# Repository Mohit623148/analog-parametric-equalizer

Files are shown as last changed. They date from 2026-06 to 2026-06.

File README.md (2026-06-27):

# 🎛️ 5-Band Analog Parametric Audio Equalizer

> A fully analog, State Variable Filter (SVF) based parametric equalizer covering the full audio spectrum (20 Hz – 20 kHz), designed as Minor Project II at NIT Andhra Pradesh.

---

## 📌 Project Overview

This project implements a **5-band analog parametric equalizer** using the **KHN (Kerwin-Huelsman-Newcomb) State Variable Filter** topology. It features independent control of center frequency, gain (±9 dB), and Q (bandwidth) for each band — without any cross-coupling between parameters.

The complete design flow covers:
- Transfer function derivation and circuit analysis
- LTspice behavioral and SPICE-level simulation
- Proteus verification with exact TL074CDR models
- KiCad schematic capture (EESchema) and 4-layer PCB layout (PCBnew)

---

## 🗂️ Repository Structure

```
analog-parametric-equalizer/
│
├── ltspice/                  # LTspice simulation files (.asc)
│   ├── full_circuit.asc      # Complete cascaded equalizer
│   ├── low_shelf.asc
│   ├── band1_250Hz.asc
│   ├── band2_800Hz.asc
│   ├── band3_2500Hz.asc
│   └── high_shelf.asc
│
├── kicad/                    # KiCad project files
│   ├── Mini_project.kicad_pro
│   ├── Mini_project.kicad_sch
│   ├── Mini_project.kicad_pcb
│   └── Mini_project.kicad_prl
│
├── docs/                     # Documentation
│   ├── Project_report.pdf    # Full 27-page project report
│   └── ppt_EQ.pptx           # Presentation slides
│
├── images/                   # Screenshots and renders
│   ├── ltspice_full_circuit.png
│   ├── kicad_schematic.png
│   ├── pcb_top_view.png
│   ├── pcb_3d_isometric.png
│   └── sim_smile_curve.png
│
└── README.md
```

---

## ⚙️ Filter Architecture

The equalizer uses a **cascaded (series)** signal chain — each filter block feeds the next, which simplifies gain staging and inter-band tuning.

```
Audio In (3.5mm TRRS)
    │
    ▼
[DC Block + Impedance Match]  →  [ESD Protection — TVS1400DRV]
    │
    ▼
[Low Shelf Filter]        fc: 120–500 Hz,    Gain: ±9 dB
    │
    ▼
[SVF Band 1 — Bass]       f₀: 120–500 Hz,   Gain: ±9 dB,  Q: adjustable
    │
    ▼
[SVF Band 2 — Midrange]   f₀: 400–1600 Hz,  Gain: ±9 dB,  Q: adjustable
    │
    ▼
[SVF Band 3 — Upper Mid]  f₀: 1.2–5 kHz,    Gain: ±9 dB,  Q: adjustable
    │
    ▼
[High Shelf Filter]        fc: 1.2–5 kHz,   Gain: ±9 dB
    │
    ▼
[Output Buffer + ESD]  →  Audio Out (3.5mm TRRS)
```

### Band Summary

| Band | Center Freq | Tuning Range | Integrator Caps | Frequency Pot |
|---|---|---|---|---|
| Low Shelf | 120–500 Hz  | Adjustable | C11 = 80 nF | RV2 (100kΩ dual)  |
| Band 1 Bass  | 250 Hz | 120–500 Hz | C3, C4 = 33 nF  | RV3/RV4 (10kΩ dual)|
| Band 2 Mid | 800 Hz | 400–1600 Hz  | C7, C8 = 10 nF  | RV7/RV9 (10kΩ dual)|
| Band 3 Hi-Mid| 2.5 kHz | 1.2–5 kHz | C9, C10 = 3.3 nF| RV10/RV12 (10kΩ dual)|
| High Shelf | 1.2–5 kHz | Adjustable | C2 = 6.8 nF | RV15 (100kΩ dual) |

---

## 🔬 Key Design Achievements

### Q–Gain Decoupling
In a standard SVF, bandpass peak = Q × Vin, meaning tuning Q inadvertently changes the boost/cut magnitude. This was solved by relocating the Q-control resistor to the BP output feedback path of the summing amplifier — peak amplitude is now constant at Vin, fully independent of Q.

### Dual-Gang Frequency Control
Center frequency ω₀ = 1/(RC) requires both integrators to track the same R simultaneously. Dual-gang potentiometers ensure both integrators always see equal resistance, maintaining SVF symmetry at any frequency setting.

### SVF Bandpass Transfer Function

```
              (ω₀/Q) · s
H(s) = ─────────────────────────────
         s² + (ω₀/Q)·s + ω₀²
```

---

## 🧰 Components

**Core ICs:**
- `TL074CDR` — Quad JFET-input op-amp, SOIC-14 (×5, giving 20 op-amp stages)
- `TVS1400DRV` — TVS ESD protection array (×2, at input and output)

**Op-Amp Key Specs (TL074CDR):**

| Parameter | Value |
|---|---|
| Supply voltage  | ±15 V |
| Slew rate | 13 V/µs |
| GBW product | 3 MHz |
| Input bias | 65 pA |
| Noise voltage | 18 nV/√Hz |

**Total BOM:** 89 components, 56 fixed resistors, 11 capacitors, 16 potentiometers, 2 audio connectors.

---

## 📊 Simulation Results

All five filter blocks were simulated in **LTspice XVII** (AC sweep, 20 Hz – 20 kHz, 1000 pts/decade) and verified in **Proteus** using exact TL074CDR SPICE models.

| Block | Target f₀/fc | Result | Gain Range | Status  |
|---|---|---|---|---|
| Low Shelf | 250 Hz nominal | ~250 Hz, tunable 120–500 Hz | ±9 dB | ✅ Pass |
| Band 1 (Bass)  | 250 Hz | ~250 Hz, tunable 120–500 Hz | ±9 dB | ✅ Pass |
| Band 2 (Mid) | 800 Hz | ~800 Hz, tunable 400–1600 Hz| ±9 dB | ✅ Pass |
| Band 3 (Hi-Mid)| 2.5 kHz | ~2.5 kHz, tunable 1.2–5 kHz | ±9 dB  | ✅ Pass |
| High Shelf | 2.3 kHz nominal| ~2.3 kHz, tunable 1.2–5 kHz | ±9 dB  | ✅ Pass |

**Preset EQ responses verified:** V-Shape (Smile Curve), Vocal Boost

---

## 🖥️ PCB Design

Designed in **KiCad PCBnew v9.0** with a 4-layer FR-4 stackup:

| Layer | Role |
|---|---|
| F.Cu (Top) | Signal routing, component placement |
| In1.Cu | Solid GND plane |
| In2.Cu | ±15 V power distribution |
| B.Cu (Bot) | Secondary signal routing |

**PCB Stats:** 1,468 track segments · 150 vias · A3 drawing sheet

Layout follows signal-flow order (left → right), with decoupling caps adjacent to op-amp supply pins and all potentiometers along one edge for front-panel mounting.

---

## 🛠️ Tools Used

| Tool | Version | Purpose |
|---|---|---|
| LTspice XVII | — | AC sweep simulation |
| Proteus Design Suite | — | SPICE verification |
| KiCad EESchema | 9.0 | Schematic capture |
| KiCad PCBnew | 9.0 | PCB layout |

---

## 👥 Team

| Name | Roll No. |
|---|---|
| Mohit Kumar Gupta | 623148 |
| Satyam Kumar | 623172 |
| Vishal Ray | 622271 |

**Guide:** Dr. M. C. Raju, Assistant Professor, DECE, NIT Andhra Pradesh
**Course:** Minor Project II (EC399) · Academic Year 2025–26

---

## 📄 License

This project is shared for educational and reference purposes. Feel free to study, fork, and build upon it — attribution appreciated.

---

## 🔮 Future Work

- [ ] PCB fabrication and hardware assembly
- [ ] Audio characterisation using REW (THD+N, noise floor, dynamic range)
- [ ] Enclosure and front-panel design for all 16 potentiometers
- [ ] Expand to 7 or 10 bands with additional SVF stages
- [ ] PCB noise optimisation based on measured results

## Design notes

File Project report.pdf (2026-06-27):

``

## NATIONAL INSTITUTE OF TECHNOLOGY ANDHRA PRADESH

Department of Electronics and Communication Engineering

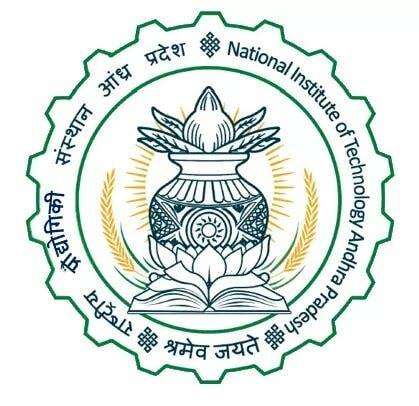
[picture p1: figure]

# Design and Implementation of a Multi-Band Analog Audio Equalizer

## PROJECT REPORT

Minor Project II (EC399)

Presented by: | Mohit Kumar Gupta [623148]
Satyam Kumar | [623172]
Vishal Ray | [622271]
Guide: | Dr. M. C. Raju Assistant Professor NIT Andhra Pradesh

Multi-Band Analog Audio Equalizer — Final Project Report | NIT Andhra Pradesh, Dept. of ECE
Page 2 of 27 | Minor Project II (EC) | April 2026

CERTIFICATE This is to certify that the project report entitled "Design and Implementation of a Multi-Band Analog Audio Equalizer" is a Bonafide record of the work carried out by Mohit Kumar Gupta (623148), Satyam Kumar (623172), and Vishal Ray (622271) in fulfilment of the requirements for the award of the degree of Bachelor of Technology in Electronics and Communication Engineering at the

National Institute of Technology Andhra Pradesh.

## This work has been carried out under my supervision during the

academic year 2025–2026.

## Guide:

Dr. M. C. Raju | Dr. B. Narasimha Rao
Assistant Professor | Head of Department
DECE | DECE
NIT Andhra Pradesh | NIT Andhra Pradesh

Page 3 of 27 | Minor Project II (EC) | April 2026

## ACKNOWLEDGEMENT

We would like to express our sincere gratitude to our project guide,

## Dr. M. C. Raju, for his continuous support, valuable guidance, and encouragement throughout the development of this project. His expertise and insights were instrumental in shaping the direction and

successful completion of this work.

## We also thank the faculty members of the Department of Electronics and Communication Engineering, NIT Andhra Pradesh, for providing

the necessary resources and a supportive academic environment.

## We would like to extend our special thanks to the judges for their valuable suggestions during the mid-review and for their time and

constructive feedback, which helped improve the quality of our work.

## We are grateful to our friends and peers for their support and constructive discussions. Finally, we extend our heartfelt thanks to

our families for their constant motivation and encouragement.

Page 4 of 27 | Minor Project II (EC) | April 2026

## ABSTRACT This project presents the design and implementation of a 5-band analog parametric audio equalizer covering the full audio frequency range from 20 Hz to 20 kHz. The system is based on the State Variable Filter (SVF) topology, enabling independent control of

center frequency, gain, and bandwidth (Q-factor) for each band.

## The equalizer consists of three tunable peaking filters centered at 250 Hz, 800 Hz, and 2.5 kHz, along with low and high shelving filters for bass and treble control. The design uses TL074 JFET-input

operational amplifiers to achieve low noise, high input impedance, and adequate bandwidth for audio applications.

## A complete signal chain is developed, including input/output interfacing through 3.5 mm TRRS audio jacks, ESD protection using TVS diodes, and proper impedance matching. The circuit is designed and verified using LTspice and Proteus simulations, followed by

schematic capture and PCB layout using KiCad.

## The results demonstrate accurate frequency response, ±9 dB gain control, and stable performance across all bands. The project highlights the practical implementation of analog filter design concepts and provides a foundation for further development into a

fully functional audio processing device.

Page 5 of 27 | Minor Project II (EC) | April 2026

## Table of Contents

Page 6 of 27 | Minor Project II (EC) | April 2026

Page 7 of 27 | Minor Project II (EC) | April 2026

## 1. Introduction

### 1.1 Background and Motivation

Audio equalization is the process of selectively adjusting the amplitude of specific frequency bands within an audio signal. It is fundamental to professional audio production, live sound reinforcement, acoustic correction, and consumer hi-fi systems. Without equalization, audio systems suffer from uneven frequency response introduced by room acoustics, speaker colorations, and source limitations — all of which degrade the perceived quality of sound.
Digital equalizers have become dominant in modern audio processing owing to their flexibility and precision. However, analog equalizers remain indispensable in applications demanding zero latency, simplicity of hardware, and the characteristic warmth that continuous-time processing preserves. For educational purposes, an analog parametric equalizer also serves as a comprehensive vehicle for applying filter theory, op-amp circuit design, and frequency-domain analysis to a real-world problem.

### 1.2 Project Objectives

- Design a 5-band analog parametric equalizer covering the full audio spectrum (20 Hz – 20 kHz).
- Implement three fully tunable SVF-based peaking bands at 250 Hz, 800 Hz, and 2.5 kHz with ±9 dB gain and adjustable Q.
- Implement low shelving and high shelving filters with tunable corner frequencies and ±9 dB gain.
- Design a complete signal chain including 3.5 mm TRRS stereo input/output jacks with impedance matching and ESD protection.
- Capture and verify the full schematic in KiCad EESchema and complete a 4-layer PCB layout in KiCad PCBnew.
- Verify all filter blocks through LTspice AC sweep simulation (20 Hz – 20 kHz) and Proteus simulation using exact TL074C SPICE models.

### 1.3 Scope of This Report

This report presents the complete design and implementation work carried out over the full duration of the Minor Project II. It covers the theoretical foundation, all circuit design decisions, simulation results, schematic and PCB design, and verification outcomes. It is structured as a single comprehensive document encompassing all work from initial architecture selection through final PCB layout.

## 2. Background and Theory

### 2.1 Types of Equalizers

Three principal equalizer architectures exist in analog audio design:
- Graphic Equalizer: Fixed center frequencies per band, typically 10 or 31 bands. Simple to operate visually using sliders but offers limited precision and fixed bandwidth.
- Parametric Equalizer: Adjustable center frequency (f₀), adjustable Q (bandwidth), and adjustable gain per band. Provides the highest precision and is standard in professional studio applications. This project implements this type.

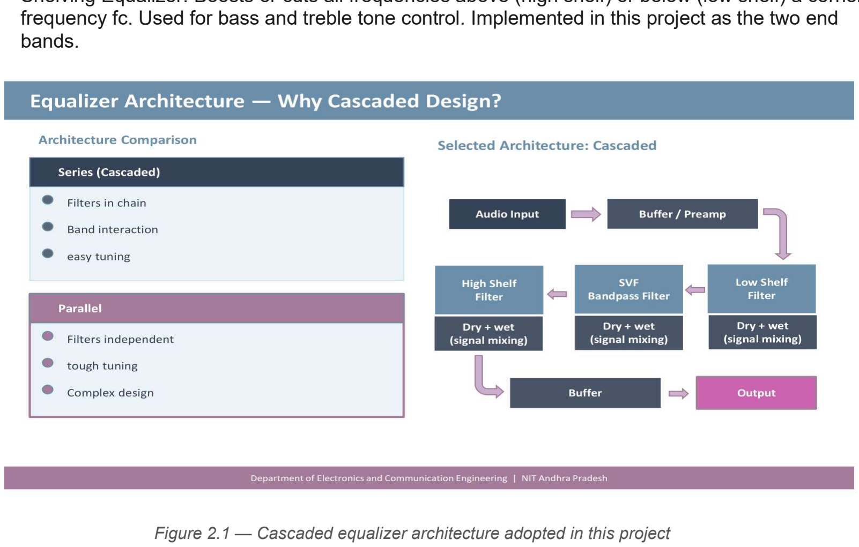
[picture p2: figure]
bands.

Page 8 of 27 | Minor Project II (EC) | April 2026
- Shelving Equalizer: Boosts or cuts all frequencies above (high shelf) or below (low shelf) a corner frequency fc. Used for bass and treble tone control. Implemented in this project as the two end

Figure 2.1 — Cascaded equalizer architecture adopted in this project

### 2.2 Analog vs Digital Equalizers

Feature | Analog Equalizer | Digital Equalizer
Signal Domain | Continuous-time | Discrete-time (sampled)
Latency | Zero latency | Processing delay present
Noise | Thermal & op-amp noise | Quantization noise
Flexibility | Fixed hardware design | Software reprogrammable
Power | Low | Higher (DSP core required)
Audio Quality | Warm, continuous-time character | Precise, bit-perfect control

### 2.3 Human Hearing and Band Selection

The human auditory system perceives pitch logarithmically and exhibits frequency-dependent loudness sensitivity (Fletcher-Munson curves). The three peaking bands in this equalizer were positioned at 250 Hz, 800 Hz, and 2.5 kHz — separated by approximately two octaves each — based on their psychoacoustic significance:
- 250 Hz (Bass band): Warmth and body of bass guitar, kick drum fundamental, male vocal chest resonance.

Page 9 of 27 | Minor Project II (EC) | April 2026
- 800 Hz (Midrange band): Male and female vocal presence, snare body, guitar midrange character.
- 2.5 kHz (Upper midrange band): Vocal intelligibility, guitar pick attack, piano clarity and definition. Two-octave spacing between bands minimises inter-band interaction, ensuring that adjusting one band does not significantly affect the response of adjacent bands.

## 3. System Architecture

### 3.1 Overall Signal Chain

A cascaded (series) architecture was selected over a parallel arrangement. In a cascaded design, each filter block processes the output of the previous one, which simplifies gain staging and makes individual band tuning straightforward. The complete signal path is:

### 3.5 mm TRRS Input Jack (J1) → DC Blocking + Impedance Matching → ESD

Protection (U1)
→ Low Shelf Filter (fc: 120–500 Hz, Gain: ±9 dB)
→ SVF Peaking Band 1 (f₀: 120–500 Hz, Q: adjustable, Gain: ±9 dB)
→ SVF Peaking Band 2 (f₀: 400–1600 Hz, Q: adjustable, Gain: ±9 dB)
→ SVF Peaking Band 3 (f₀: 1.2–5 kHz, Q: adjustable, Gain: ±9 dB)
→ High Shelf Filter (fc: 1.2–5 kHz, Gain: ±9 dB)
→ Output Buffer (R4=100Ω) → ESD Protection (U2) → 3.5 mm TRRS Output Jack (J2)

### 3.2 Op-Amp Selection — TL074CDR

The TL074CDR (Texas Instruments) quad JFET-input op-amp was selected as the core active element for all filter stages. Five ICs provide 20 op-amp units for the entire signal chain.

Parameter | TL074CDR Value | Significance
Supply voltage | ±15 V | Full ±13 V output swing for audio levels
Slew rate | 13 V/µs | Adequate for 20 kHz full-scale signal
GBW product | 3 MHz | Sufficient gain margin at audio frequencies
Input bias current | 65 pA | Negligible DC error across RC filter networks
Noise voltage | 18 nV/√Hz | Low noise floor suitable for audio
Input offset voltage | 3 mV | Minimal DC offset at filter outputs
Package | SOIC-14 (CDR) | Used in PCB layout; compact SMD footprint
Channels per IC | 4 | 5 ICs = 20 op-amp stages total

## 4. Filter Design and Analysis

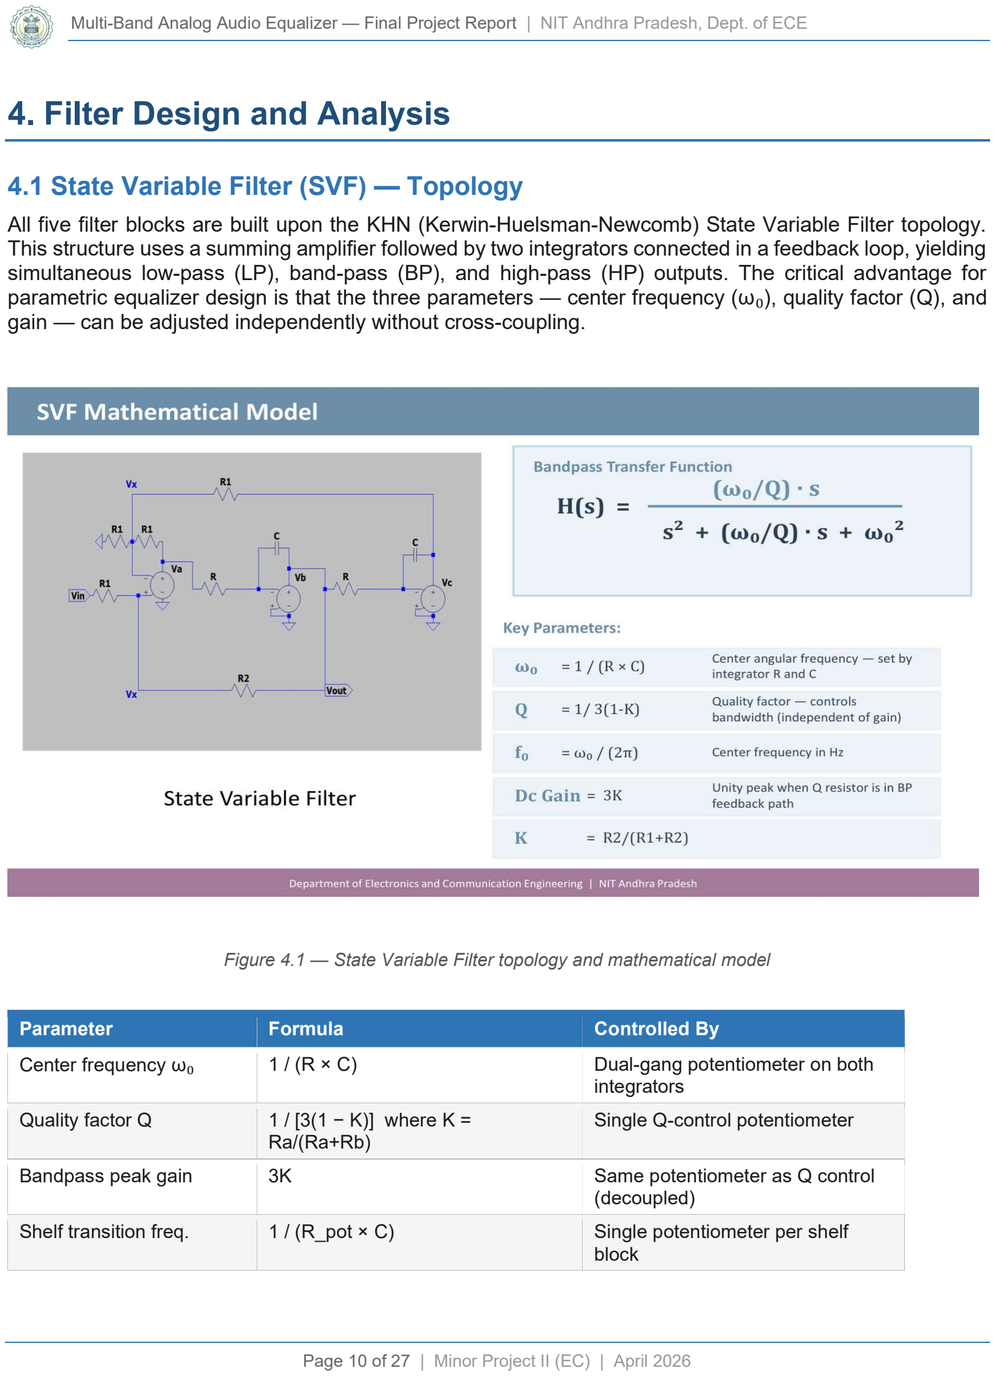
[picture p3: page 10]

Page 10 of 27 | Minor Project II (EC) | April 2026

### 4.1 State Variable Filter (SVF) — Topology

All five filter blocks are built upon the KHN (Kerwin-Huelsman-Newcomb) State Variable Filter topology. This structure uses a summing amplifier followed by two integrators connected in a feedback loop, yielding simultaneous low-pass (LP), band-pass (BP), and high-pass (HP) outputs. The critical advantage for parametric equalizer design is that the three parameters — center frequency (ω₀), quality factor (Q), and gain — can be adjusted independently without cross-coupling.

Figure 4.1 — State Variable Filter topology and mathematical model

Parameter | Formula | Controlled By
Center frequency ω₀ | 1 / (R × C) | Dual-gang potentiometer on both integrators
Quality factor Q | 1 / [3(1 − K)] where K = Ra/(Ra+Rb) | Single Q-control potentiometer
Bandpass peak gain | 3K | Same potentiometer as Q control (decoupled)
Shelf transition freq. | 1 / (R_pot × C) | Single potentiometer per shelf block

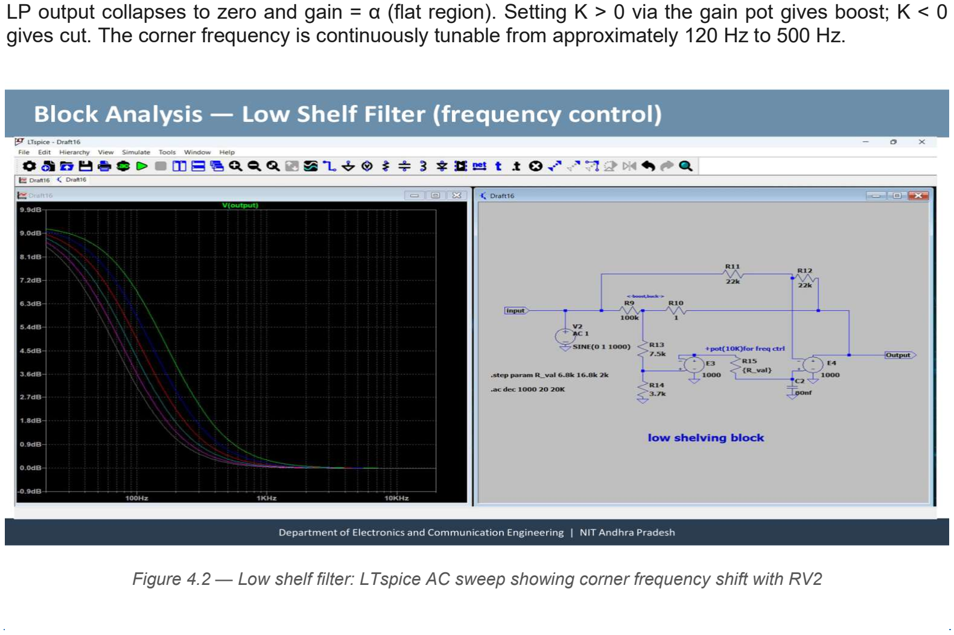
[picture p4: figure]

Page 11 of 27 | Minor Project II (EC) | April 2026

### 4.1.1 Q–Gain Decoupling — Key Design Achievement

In a standard SVF, the bandpass output peak amplitude equals Q × Vin. This means that increasing Q to narrow the bandwidth simultaneously increases the boost magnitude — an unacceptable coupling in a parametric equalizer. This problem was solved by repositioning the Q-control resistor into the BP output feedback path of the summing amplifier rather than within the SVF loop itself. With this modification, the peak amplitude remains constant at Vin regardless of the Q setting, achieving fully independent Q and gain control.

### 4.1.2 Dual-Gang Frequency Control

The center frequency ω₀ = 1/(RC) requires that both integrators in the SVF track exactly the same R value. Using two independent potentiometers would make simultaneous matching impossible in practice. Dual-gang potentiometers (one shaft driving two identical wiper tracks) ensure that both integrators always see equal resistance values, maintaining perfect SVF symmetry and a clean, undistorted filter response at any frequency setting.

### 4.2 Low Shelving Filter

The low shelving filter boosts or cuts all frequencies below its adjustable corner frequency fc. Architecturally, the SVF LP output is scaled by gain factor K and summed with the unfiltered dry signal. The resulting transfer function is:
H(s) = α + K.
()
| ωο =
Behaviour: at f << fc the LP output tracks the input and total gain = α + K (boost/cut region). At f >> fc the LP output collapses to zero and gain = α (flat region). Setting K > 0 via the gain pot gives boost; K < 0 gives cut. The corner frequency is continuously tunable from approximately 120 Hz to 500 Hz.

Figure 4.2 — Low shelf filter: LTspice AC sweep showing corner frequency shift with RV2

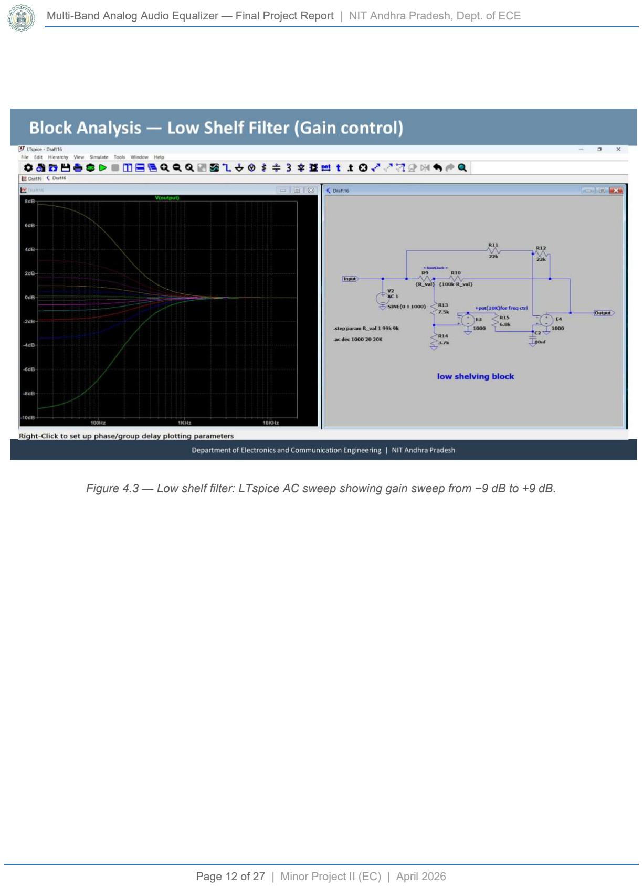
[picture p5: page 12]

Page 12 of 27 | Minor Project II (EC) | April 2026

Figure 4.3 — Low shelf filter: LTspice AC sweep showing gain sweep from −9 dB to +9 dB.

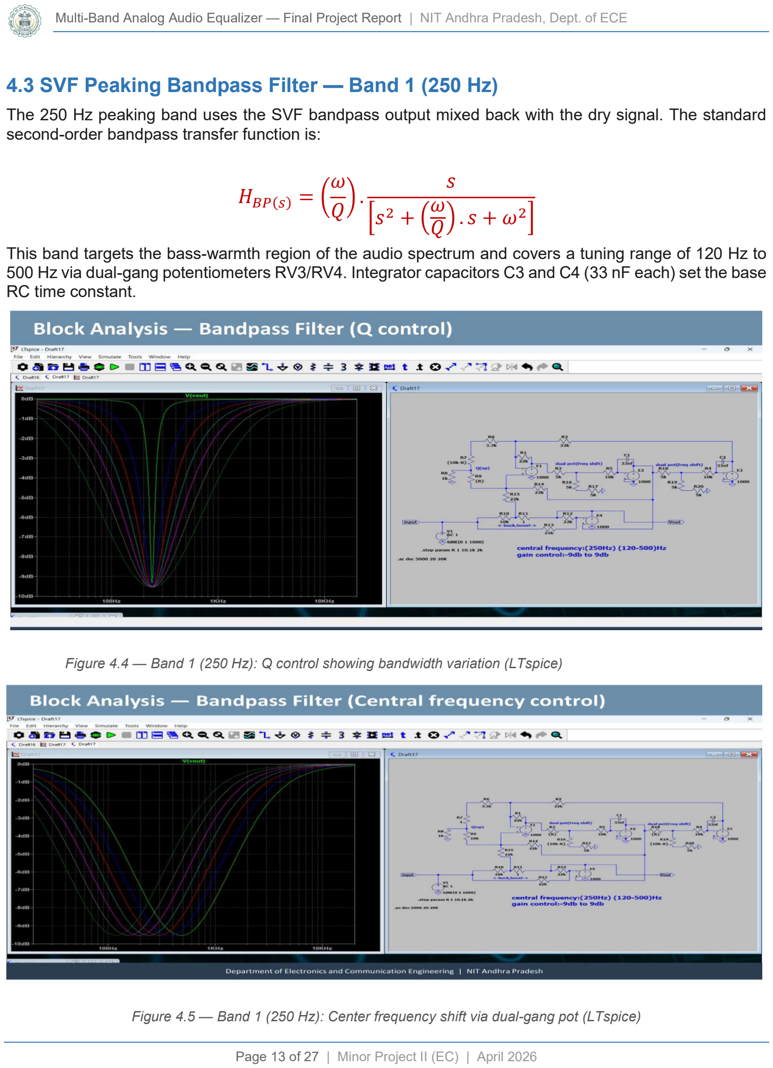
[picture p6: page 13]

Page 13 of 27 | Minor Project II (EC) | April 2026

### 4.3 SVF Peaking Bandpass Filter — Band 1 (250 Hz)

The 250 Hz peaking band uses the SVF bandpass output mixed back with the dry signal. The standard second-order bandpass transfer function is:

H() =

ω
Q

s
s
+

ω
Q

. s + ω

This band targets the bass-warmth region of the audio spectrum and covers a tuning range of 120 Hz to 500 Hz via dual-gang potentiometers RV3/RV4. Integrator capacitors C3 and C4 (33 nF each) set the base RC time constant.

Figure 4.4 — Band 1 (250 Hz): Q control showing bandwidth variation (LTspice)

Figure 4.5 — Band 1 (250 Hz): Center frequency shift via dual-gang pot (LTspice)

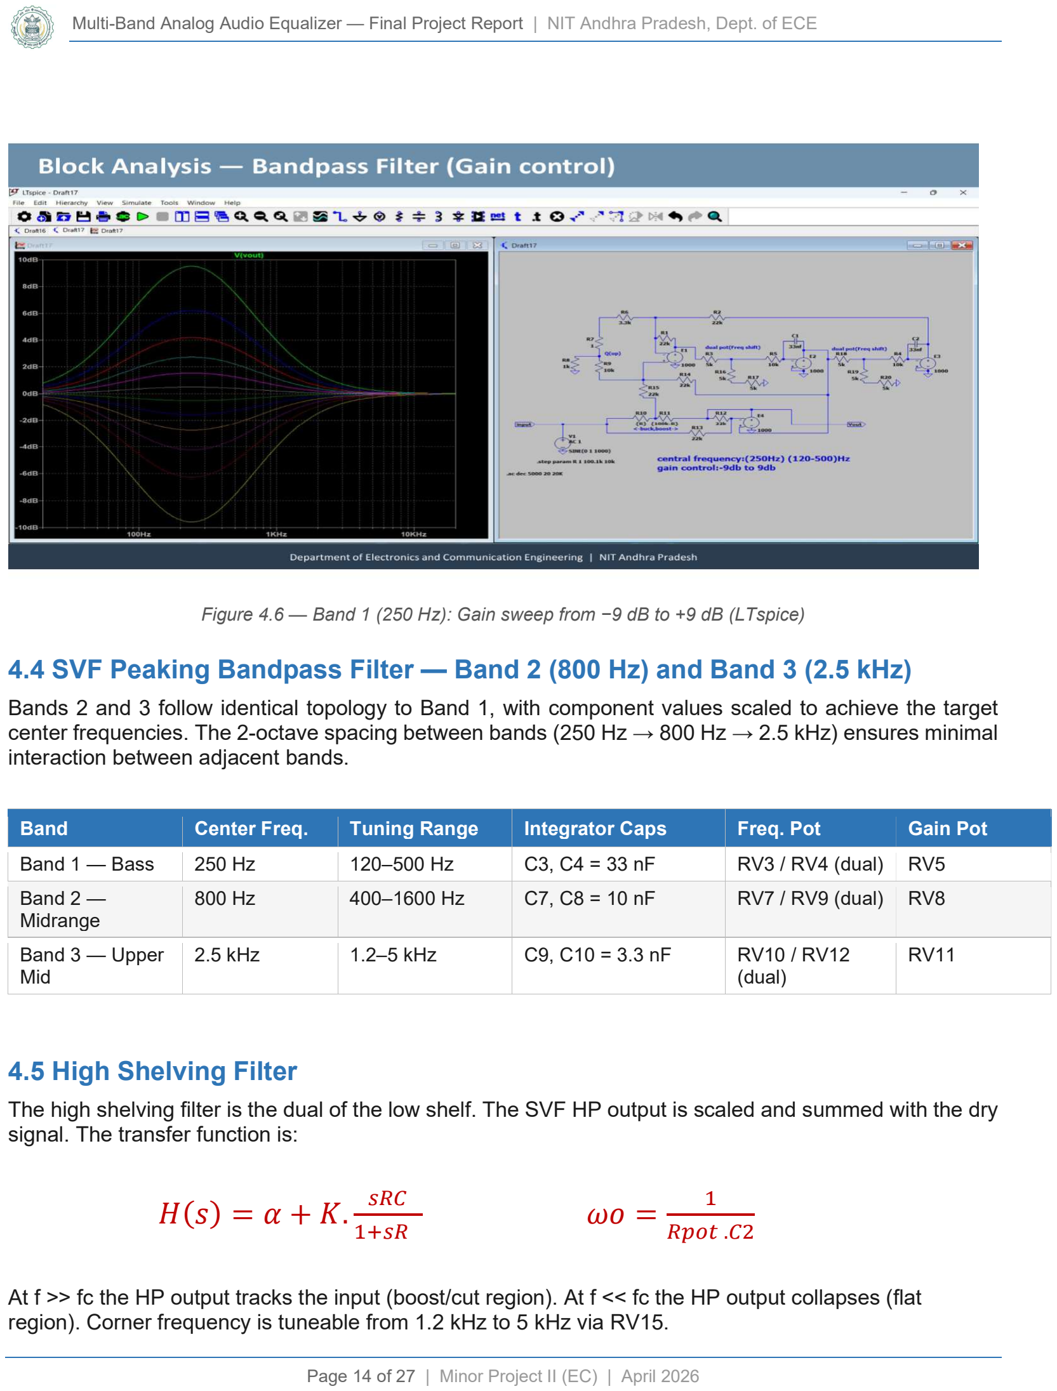
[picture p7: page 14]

Page 14 of 27 | Minor Project II (EC) | April 2026

Figure 4.6 — Band 1 (250 Hz): Gain sweep from −9 dB to +9 dB (LTspice)

### 4.4 SVF Peaking Bandpass Filter — Band 2 (800 Hz) and Band 3 (2.5 kHz)

Bands 2 and 3 follow identical topology to Band 1, with component values scaled to achieve the target center frequencies. The 2-octave spacing between bands (250 Hz → 800 Hz → 2.5 kHz) ensures minimal interaction between adjacent bands.

Band | Center Freq. | Tuning Range | Integrator Caps | Freq. Pot | Gain Pot
Band 1 — Bass | 250 Hz | 120–500 Hz | C3, C4 = 33 nF | RV3 / RV4 (dual) | RV5
Band 2 — Midrange | 800 Hz | 400–1600 Hz | C7, C8 = 10 nF | RV7 / RV9 (dual) | RV8
Band 3 — Upper Mid | 2.5 kHz | 1.2–5 kHz | C9, C10 = 3.3 nF | RV10 / RV12 (dual) | RV11

### 4.5 High Shelving Filter

The high shelving filter is the dual of the low shelf. The SVF HP output is scaled and summed with the dry signal. The transfer function is:

H(s) = α + K.

ωo =

At f >> fc the HP output tracks the input (boost/cut region). At f << fc the HP output collapses (flat region). Corner frequency is tuneable from 1.2 kHz to 5 kHz via RV15.

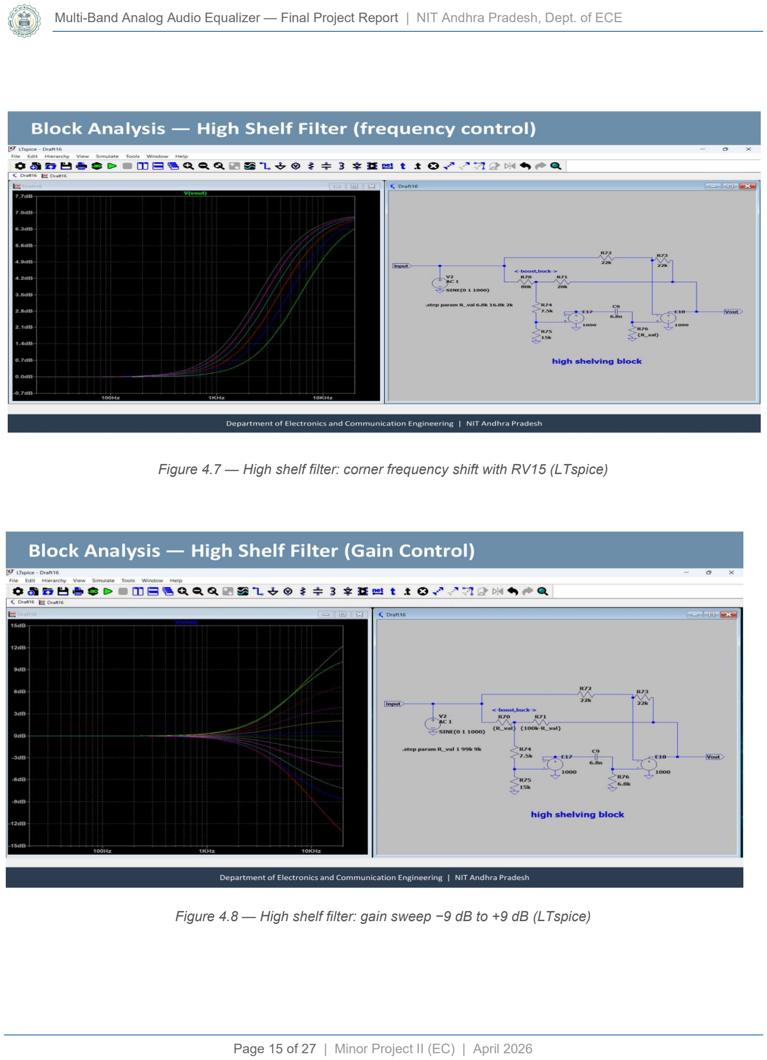
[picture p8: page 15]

Page 15 of 27 | Minor Project II (EC) | April 2026

Figure 4.7 — High shelf filter: corner frequency shift with RV15 (LTspice)

Figure 4.8 — High shelf filter: gain sweep −9 dB to +9 dB (LTspice)

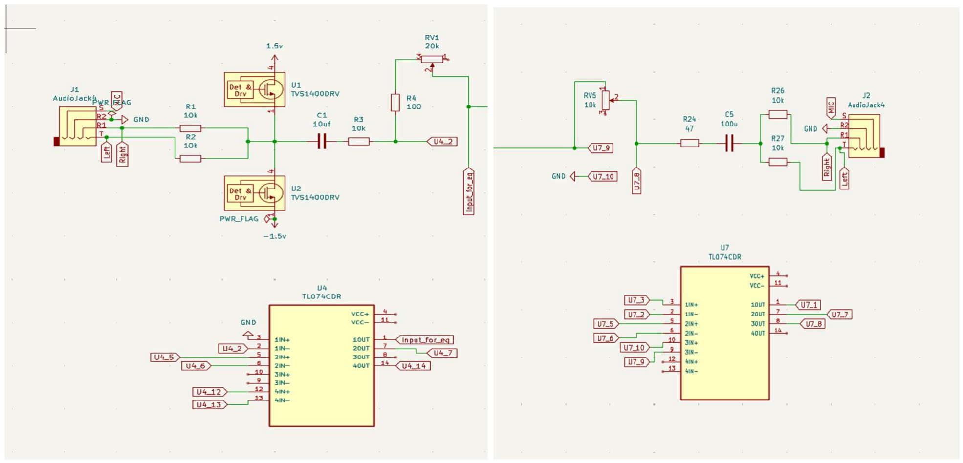
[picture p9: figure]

Page 16 of 27 | Minor Project II (EC) | April 2026

## 5. Input/Output Interface Design

### 5.1 Input Stage — 3.5 mm TRRS Jack

J1 is a 4-pole TRRS (Tip-Ring-Ring-Sleeve) 3.5 mm female audio jack. The TRRS pinout follows the CTIA standard: Tip = Left audio, Ring 1 = Right audio, Ring 2 = Microphone, Sleeve = Ground. The input accepts audio from any consumer device — smartphone, laptop, tablet, or portable media player.
A 10 µF electrolytic DC-blocking capacitor (C1) in series removes any DC bias present at the source output. The signal then passes through a voltage divider formed by R1 and R2 (both 10 kΩ), presenting an input impedance of approximately 5 kΩ to the source. This is sufficiently high to avoid loading a standard headphone output (32–100 Ω source impedance) while attenuating the signal to an op-amp-compatible level.

### 5.2 ESD Protection — TVS1400DRV

TVS1400DRV transient voltage suppressor arrays (U1 at input, U2 at output) clamp ESD transients to safe levels. These bidirectional devices protect the TL074CDR op-amp inputs and the user's source device against electrostatic discharge events that occur during hot-plugging of audio connectors. Placement is immediately adjacent to the audio jack footprints to minimise the unprotected trace length.

### 5.3 Output Stage — 3.5 mm TRRS Jack

J2 is a second 4-pole TRRS 3.5 mm female jack providing the equalizer output. The signal is buffered by the final TL074 stage. R4 (100 Ω) in series with the output ensures stability when driving capacitive loads such as headphone cables (typically 100–400 pF). The output can directly drive 32 Ω headphones from the op-amp output swing, or it can be connected to the input of an external power amplifier for loudspeaker use. C5 (100 µF) and R24 (47 Ω) form a supply decoupling filter for this output section.

Figure 5.1 — KiCad schematic: input(left) and output(right) interface stage.

Page 17 of 27 | Minor Project II (EC) | April 2026

## 6. Bill of Materials

All components listed below are as captured in the KiCad schematic (version 9.0). Resistors are 1% tolerance metal-film; capacitors are polyester/polypropylene film type unless noted. Total component count: 89 footprints across 368 nets.

### 6.1 Integrated Circuits

Ref. | Part Number | Description | Qty
U3–U7 | TL074CDR | Quad JFET-input op-amp, SOIC-14 | 5
U1, U2 | TVS1400DRV | TVS ESD protection diode array | 2

### 6.2 Fixed Resistors

Ref. | Value | Function
R1, R2 | 10 kΩ | Input voltage divider — impedance matching
R3, R36, R48 | 10 kΩ | SVF summing node resistors (Bands 1–3)
R4 | 100 Ω | Output series resistor — headphone load stability
R5, R8, R10, R15,
R17–R22, R30–R35,
R42–R47, R54, R56
| 22 kΩ | SVF feedback and summing network
R6, R52 | 7.5 kΩ | Shelf filter stability resistors
R7 | 15 kΩ | Low shelf stability
R9, R55 | 6.8 kΩ | Shelf integrator input resistors
R11, R16, R38, R50 | 5 kΩ | SVF output network
R12, R29, R41 | 3.3 kΩ | SVF input resistors
R13, R28, R40 | 1 kΩ | SVF feedback scaling
R14, R17, R26, R27,
R39, R51 | 10 kΩ | SVF node / summing resistors
R24 | 47 Ω | Power supply decoupling
R53 | 3.7 kΩ | High shelf stability

### 6.3 Potentiometers (Controls)

Ref. | Value | Function
RV1 | 20 kΩ | Low shelf gain control (boost / cut ±9 dB)
RV2 | 100 kΩ dual gang | Low shelf corner frequency (120–500 Hz)
RV3, RV4 | 10 kΩ dual gang | Band 1 center frequency (120–500 Hz)

Page 18 of 27 | Minor Project II (EC) | April 2026
Ref. | Value | Function
RV5 | 10 kΩ | Band 1 gain control (±9 dB)
RV7, RV9 | 10 kΩ dual gang | Band 2 center frequency (400–1600 Hz)
RV8 | 10 kΩ | Band 2 gain control (±9 dB)
RV10, RV12 | 10 kΩ dual gang | Band 3 center frequency (1.2–5 kHz)
RV11 | 10 kΩ | Band 3 gain control (±9 dB)
RV13, RV14 | 10 kΩ | Q control (bandwidth) for Bands 1 and 2
RV15 | 100 kΩ dual gang | High shelf corner frequency (1.2–5 kHz)
RV16 | 10 kΩ | High shelf gain control (boost / cut ±9 dB)

### 6.4 Capacitors

Ref. | Value | Type / Function
C1 | 10 µF | Electrolytic — input DC blocking
C2 | 6.8 nF | Film — high shelf integrator
C3, C4 | 33 nF | Film — Band 1 (250 Hz) integrators (×2)
C5 | 100 µF | Electrolytic — output power supply decoupling
C7, C8 | 10 nF | Film — Band 2 (800 Hz) integrators (×2)
C9, C10 | 3.3 nF | Film — Band 3 (2.5 kHz) integrators (×2)
C11 | 80 nF | Film — low shelf integrator

### 6.5 Connectors

Ref. | Part | Description
J1 | AudioJack4 (TRRS 3.5 mm,
| female) | Stereo input from phone / laptop / any consumer source
J2 | AudioJack4 (TRRS 3.5 mm,
| female) | Stereo output to headphones or power amplifier input

Page 19 of 27 | Minor Project II (EC) | April 2026

## 7. KiCad Schematic and PCB Design

### 7.1 Schematic Capture — KiCad EESchema

The complete circuit was formally captured as a schematic in KiCad EESchema (version 9.0). The schematic encompasses all five filter blocks, the input/output interface, power supply connections, TVS protection, and decoupling networks.

Parameter | Value
Tool | KiCad EESchema v9.0
Total components (BOM) | 89 footprints
Total nets | 368
Op-amp ICs (TL074CDR) | 5 (U3–U7) — 20 op-amp units total
Potentiometers | 16 (RV1–RV16)
Fixed resistors | 56
Capacitors | 11
Audio connectors | 2 (J1, J2 — TRRS 3.5 mm)
TVS protection ICs | 2 (U1, U2)

### 7.2 PCB Layout — KiCad PCBnew

Following schematic capture, a full PCB layout was completed in KiCad PCBnew (version 9.0). A 4-layer stackup was chosen to provide dedicated power and ground planes, reducing supply noise and crosstalk between the sensitive analog filter stages.

### 7.2.1 Layer Stackup

Layer | Name | Role
Layer 1 (Top) | F. Cu | Primary signal routing, all component placement (SMD)
Layer 2 (Inner 1) | In1.Cu | Solid GND plane — continuous low-impedance return path
Layer 3 (Inner 2) | In2.Cu | Power plane — ±15 V rail distribution
Layer 4 (Bottom) | B. Cu | Secondary signal routing

### 7.2.2 PCB Statistics

PCB Parameter | | Specification
PCB tool | | KiCad PCBnew v9.0
Board stackup | | 4-layer FR-4

Page 20 of 27 | Minor Project II (EC) | April 2026
PCB Parameter | Specification
Total board thickness | 1.786 mm
Copper — outer layers | 43 µm (F. Cu, B. Cu)
Copper — inner layers | 35 µm (In1.Cu, In2.Cu)
Solder mask | Both sides (εr = 3.5)
Silk screen | Both sides (component ref. labels)
Total track segments | 1,468
Total vias | 150
Drawing sheet | A3

### 7.2.3 Layout Strategy

- Filter stages are arranged in signal-flow order (left to right) to minimise long return paths.
- Decoupling capacitors (C5, C11) are placed immediately adjacent to op-amp power supply pins.
- Audio input and output connectors (J1, J2) are placed on opposite edges of the board for clean front-panel mounting.
- TVS protection ICs (U1, U2) are located directly adjacent to audio jack footprints, minimising the unprotected trace length.
- All filter capacitors (C2–C4, C7–C10) are placed within 5 mm of their associated op-amp integrator stage.
- Potentiometers (RV1–RV16) are arranged along one edge of the board for front-panel mounting through an enclosure.
- The inner GND plane (In1.Cu) provides a continuous low-impedance return beneath all op-amp stages, suppressing common-mode interference.

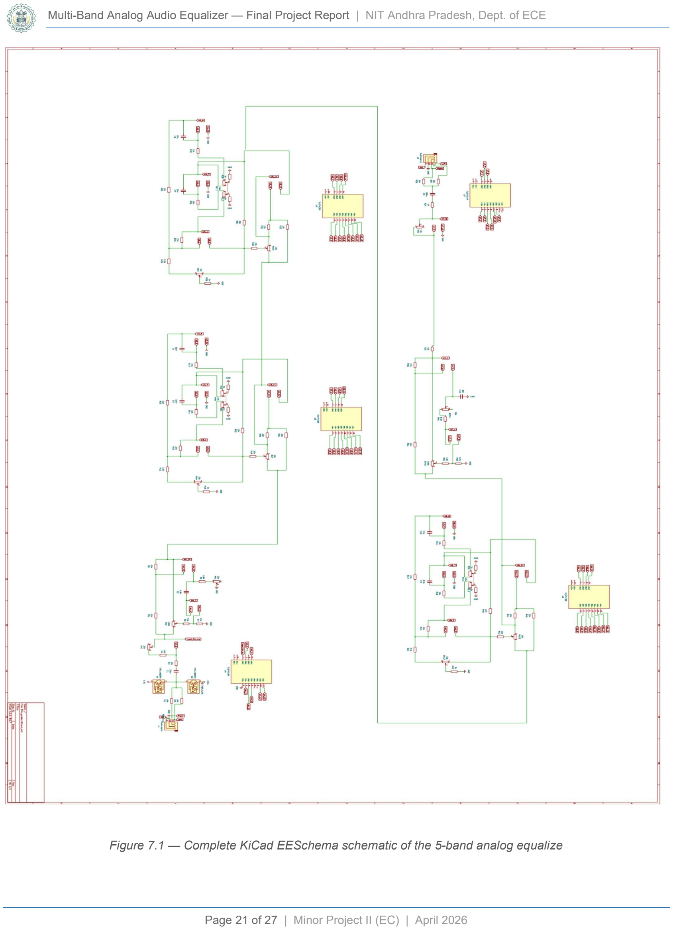
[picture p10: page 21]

Page 21 of 27 | Minor Project II (EC) | April 2026

Figure 7.1 — Complete KiCad EESchema schematic of the 5-band analog equalize

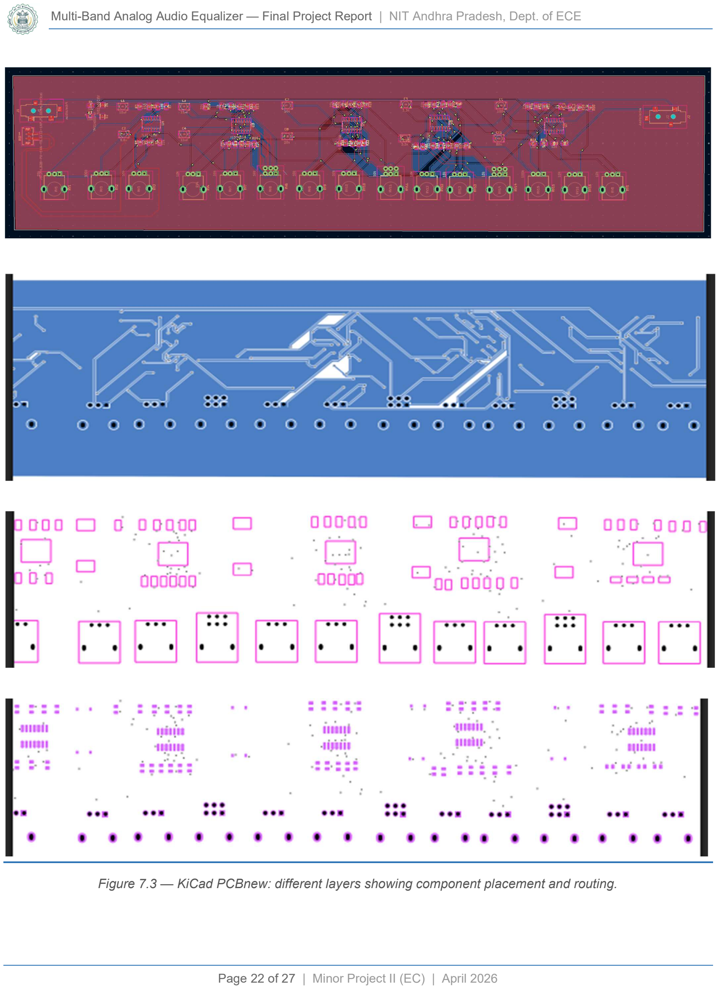
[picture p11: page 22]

Page 22 of 27 | Minor Project II (EC) | April 2026

Figure 7.3 — KiCad PCBnew: different layers showing component placement and routing.

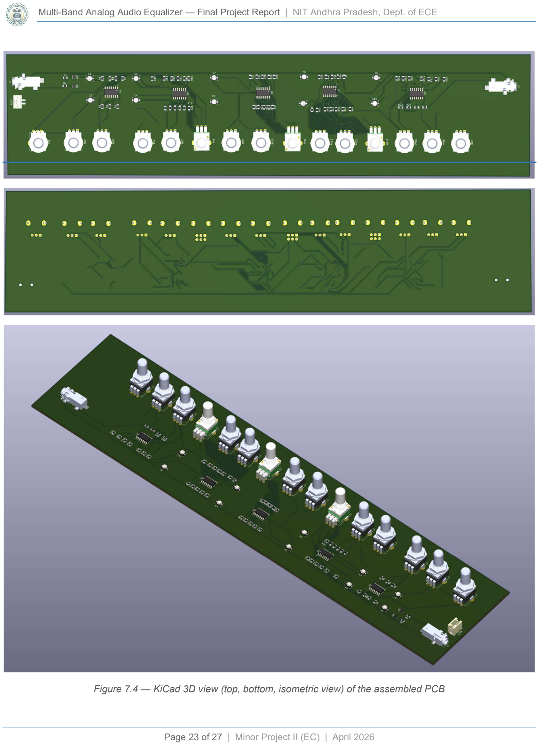
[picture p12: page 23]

Page 23 of 27 | Minor Project II (EC) | April 2026

Figure 7.4 — KiCad 3D view (top, bottom, isometric view) of the assembled PCB

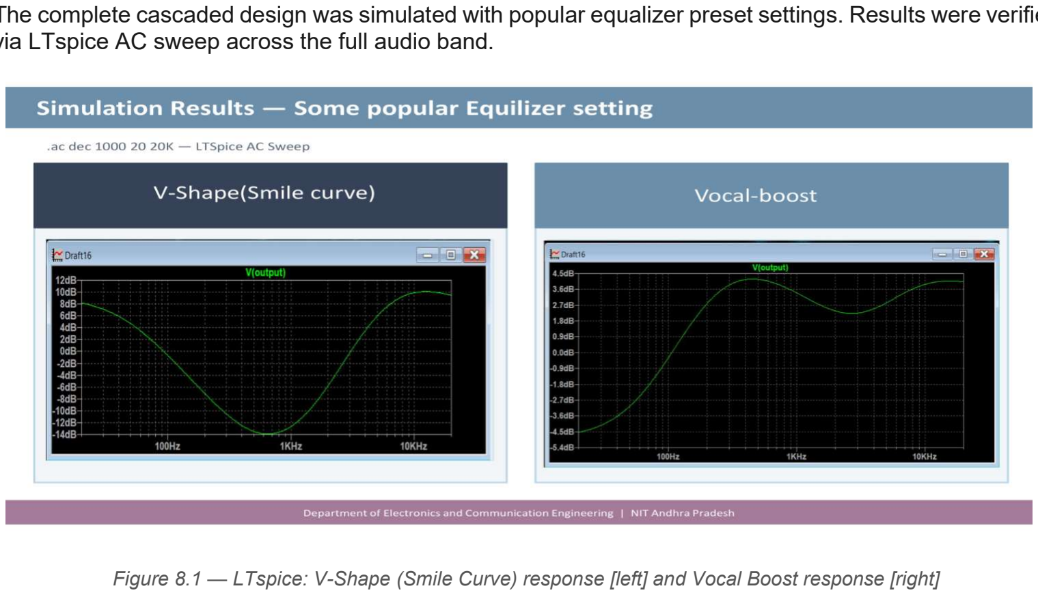
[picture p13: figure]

Page 24 of 27 | Minor Project II (EC) | April 2026

## 8. Simulation Results

### 8.1 LTspice AC Sweep — Individual Block Verification

Each filter block was independently simulated in LTspice XVII using AC analysis from 20 Hz to 20 kHz (1000 points per decade). Initial verification used behavioral VCVS (Voltage Controlled Voltage Source) models to confirm topology and transfer function behaviour. These were subsequently replaced with the exact TL074CDR SPICE model for final verification.

Block | Target f₀ / fc | Simulated Result | Gain Range Achieved

Status

Low Shelf | 250 Hz nominal | ~250 Hz, tunable 120– 500 Hz
−9 to +9 dB | ✓ Pass
Band 1 (Bass) | 250 Hz | ~250 Hz, tunable 120– 500 Hz
−9 to +9 dB | ✓ Pass
Band 2 (Midrange) | 800 Hz | ~800 Hz, tunable 400– 1600 Hz
−9 to +9 dB | ✓ Pass
Band 3 (Upper Mid) | 2.5 kHz | ~2.5 kHz, tunable 1.2–5 kHz
−9 to +9 dB | ✓ Pass
High Shelf | 2.3 kHz nominal | ~2.3 kHz, tunable 1.2–5 kHz
−9 to +9 dB | ✓ Pass

### 8.2 Preset EQ Response Verification

The complete cascaded design was simulated with popular equalizer preset settings. Results were verified via LTspice AC sweep across the full audio band.

Figure 8.1 — LTspice: V-Shape (Smile Curve) response [left] and Vocal Boost response [right]

Page 25 of 27 | Minor Project II (EC) | April 2026
- V-Shape (Smile Curve): Low shelf and high shelf at +9 dB, all three peaking bands at −9 dB. Result: bass and treble boosted, midrange attenuated — characteristic smile-curve response confirmed.
- Vocal Boost: Band 2 (800 Hz) and Band 3 (2.5 kHz) at moderate boost (+4 to +5 dB), Band 1 at slight cut, shelves at moderate settings. Result: enhanced midrange presence and vocal intelligibility confirmed.

### 8.3 Proteus Verification — Exact Component Models

Following LTspice verification, the complete circuit was simulated in Proteus Design Suite using the exact TL074C SPICE model replacing all behavioral sources. Simulation results confirmed that the design meets all specifications under realistic device parameters:
- Frequency response: All five bands achieved target center frequencies and gain ranges, matching LTspice predictions within ±2%.
- Slew rate: The TL074C slew rate of 13 V/µs was confirmed adequate — no slew-induced distortion observed at 20 kHz full-scale.
- Op-amp output swing: Confirmed ±13 V output swing under ±15 V supply, providing adequate headroom for audio levels.
- DC offset: Measured output DC offset < 5 mV across all stages — negligible for audio applications.
Overall, Proteus simulation results match LTspice predictions, validating the design and confirming readiness for PCB fabrication.

## 9. Challenges Faced and Solutions

Challenge | Problem | Solution
Q–Gain Coupling | In standard SVF, BP peak = Q × Vin. Tuning Q inadvertently changes boost/cut magnitude. | Q-control resistor relocated to the BP output feedback path of the summing amplifier. Peak amplitude is now constant at Vin, fully decoupled from Q.
Flat Response at Centre Pot | At the mid-position of the gain pot, the dry and wet signal paths must exactly cancel for a true 0 dB response. Resistor mismatch causes residual gain error. | Gain network resistors (R11, R16, R28, R29, R38, R50) carefully ratio-matched in simulation to achieve symmetric ±9 dB swing centred on 0 dB.

Frequency Control
Coupling

Changing only one
integrator's resistance
breaks SVF loop symmetry,
distorting filter shape and shifting effective Q.

Dual-gang potentiometers used for all frequency controls (RV2, RV3/RV4, RV7/RV9, RV10/RV12, RV15) — both integrators always track equal RC time constants.

Shelf Filter
Precision

Conventional Baxandall tone controls have imprecise fc, gain-frequency interaction,

Replaced with SVF-based shelves — LP output (low shelf) and HP output (high shelf) each

Page 26 of 27 | Minor Project II (EC) | April 2026
Challenge | Problem | Solution
| and limited independent control. | summed with the dry signal, giving full independent gain and frequency control.
Input Impedance Mismatch | Consumer source devices have low-impedance headphone outputs. A too- low load causes current limiting and distortion at the source. | 10 µF DC-blocking capacitor + 10 kΩ voltage divider (R1, R2) presents ~5 kΩ input impedance — safe for all consumer audio outputs.

ESD at Audio
Connectors

Hot-plugging 3.5 mm jacks
generates transients up to several hundred volts,
capable of destroying op-amp input stages.

TVS1400DRV arrays (U1, U2) at both jacks clamp transients to safe levels before they reach any active device.

## 10. Future Scope

### 10.1 Hardware Fabrication and Assembly

The PCB design will be sent for fabrication. Assembly will use TL074CDR op-amps and all components specified in the BOM (Section 6) on ±15 V regulated supply rails. Initial functional testing will use a signal generator as the audio source and an oscilloscope or audio analyser to measure the frequency response at each stage output.

### 10.2 Audio Characterisation

The assembled board will be characterised using real audio signals — pink noise, music, and swept sine tones. Frequency response, THD+N (total harmonic distortion plus noise), dynamic range, and noise floor will be measured using audio analysis software such as REW (Room EQ Wizard) and compared against simulation predictions to fully validate the design.

### 10.3 PCB Noise Optimisation

Based on measured results, component values and PCB layout may be refined to reduce noise floor. Attention will be given to supply decoupling placement, ground loop elimination, and shielding of high-gain stages.

### 10.4 Enclosure and Panel Design

A suitable enclosure will be designed with front-panel cutouts for all 16 potentiometers and both 3.5 mm audio jacks, producing a standalone consumer-grade audio device.

### 10.5 Extended Band Count

As a future extension, the architecture can be expanded to 7 or 10 bands by adding additional SVF peaking stages. An input buffer/preamp and output makeup gain amplifier would also be incorporated for professional-grade signal handling.

Page 27 of 27 | Minor Project II (EC) | April 2026

## 11. Conclusion

This report presents the complete design and implementation of a 5-band analog parametric audio equalizer. Starting from a theoretical foundation in State Variable Filter (KHN) topology and audio frequency perception, the project progressed through analytical transfer function derivation, behavioral VCVS simulation in LTspice, replacement with exact TL074CDR op-amp models, formal schematic capture in KiCad EESchema, and complete 4-layer PCB layout in KiCad PCBnew.
The five filter blocks — a low shelving filter, three tunable SVF peaking bands at 250 Hz, 800 Hz, and 2.5 kHz, and a high shelving filter — each provide ±9 dB of gain control and tunable center/corner frequency via dual-gang potentiometers. A key design achievement is the Q–gain decoupled architecture, where bandwidth and boost/cut magnitude are fully independent. The addition of a proper input/output interface with 3.5 mm TRRS jacks, TVS ESD protection, and headphone-compatible output completes the transition from a laboratory circuit to a self-contained, usable audio device.
Simulation in both LTspice and Proteus using exact component models confirmed that all specifications are met across the full 20 Hz – 20 kHz audio band. The KiCad schematic (89 components, 368 nets) and 4-layer PCB layout (1,468 track segments, 150 vias) represent a complete, fabrication-ready design. Remaining steps — PCB fabrication, assembly, and audio-domain characterisation — will finalise the project as a working hardware prototype.

### References

- Zolzer, U. (2008). Digital Audio Signal Processing. Wiley.
- Lancaster, D. (1975). Active Filter Cookbook. Howard W. Sams.
- Tow, J. (1968). Active RC Filters — A State-Space Realization. Proc. IEEE.
- Thomas, L. C. (1971). The Biquad: Part I. IEEE Trans. Circuit Theory.
- Texas Instruments. TL074C Datasheet (SLOS081H). ti.com.
- KiCad EDA Suite, Version 9.0. kicad.org.
- LTspice XVII. Analog Devices.
- Proteus Design Suite. Labcenter Electronics.

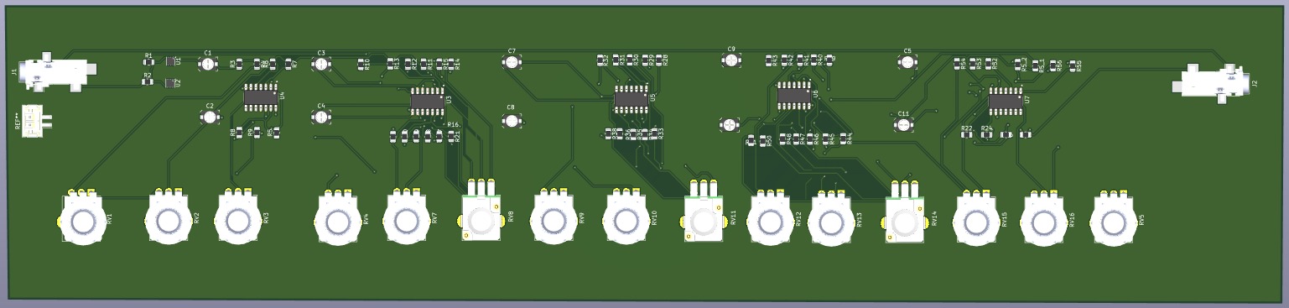
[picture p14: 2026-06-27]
WhatsApp Image 2026-06-27 at 3.43.23 PM.jpeg

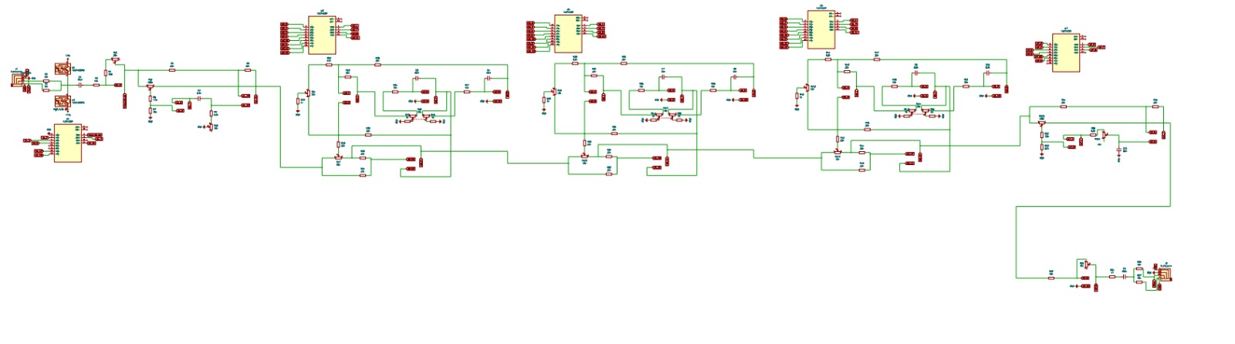
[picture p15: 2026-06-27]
WhatsApp Image 2026-04-07 at 7.07.56 PM.jpeg

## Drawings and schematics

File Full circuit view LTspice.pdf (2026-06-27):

# high shelving block

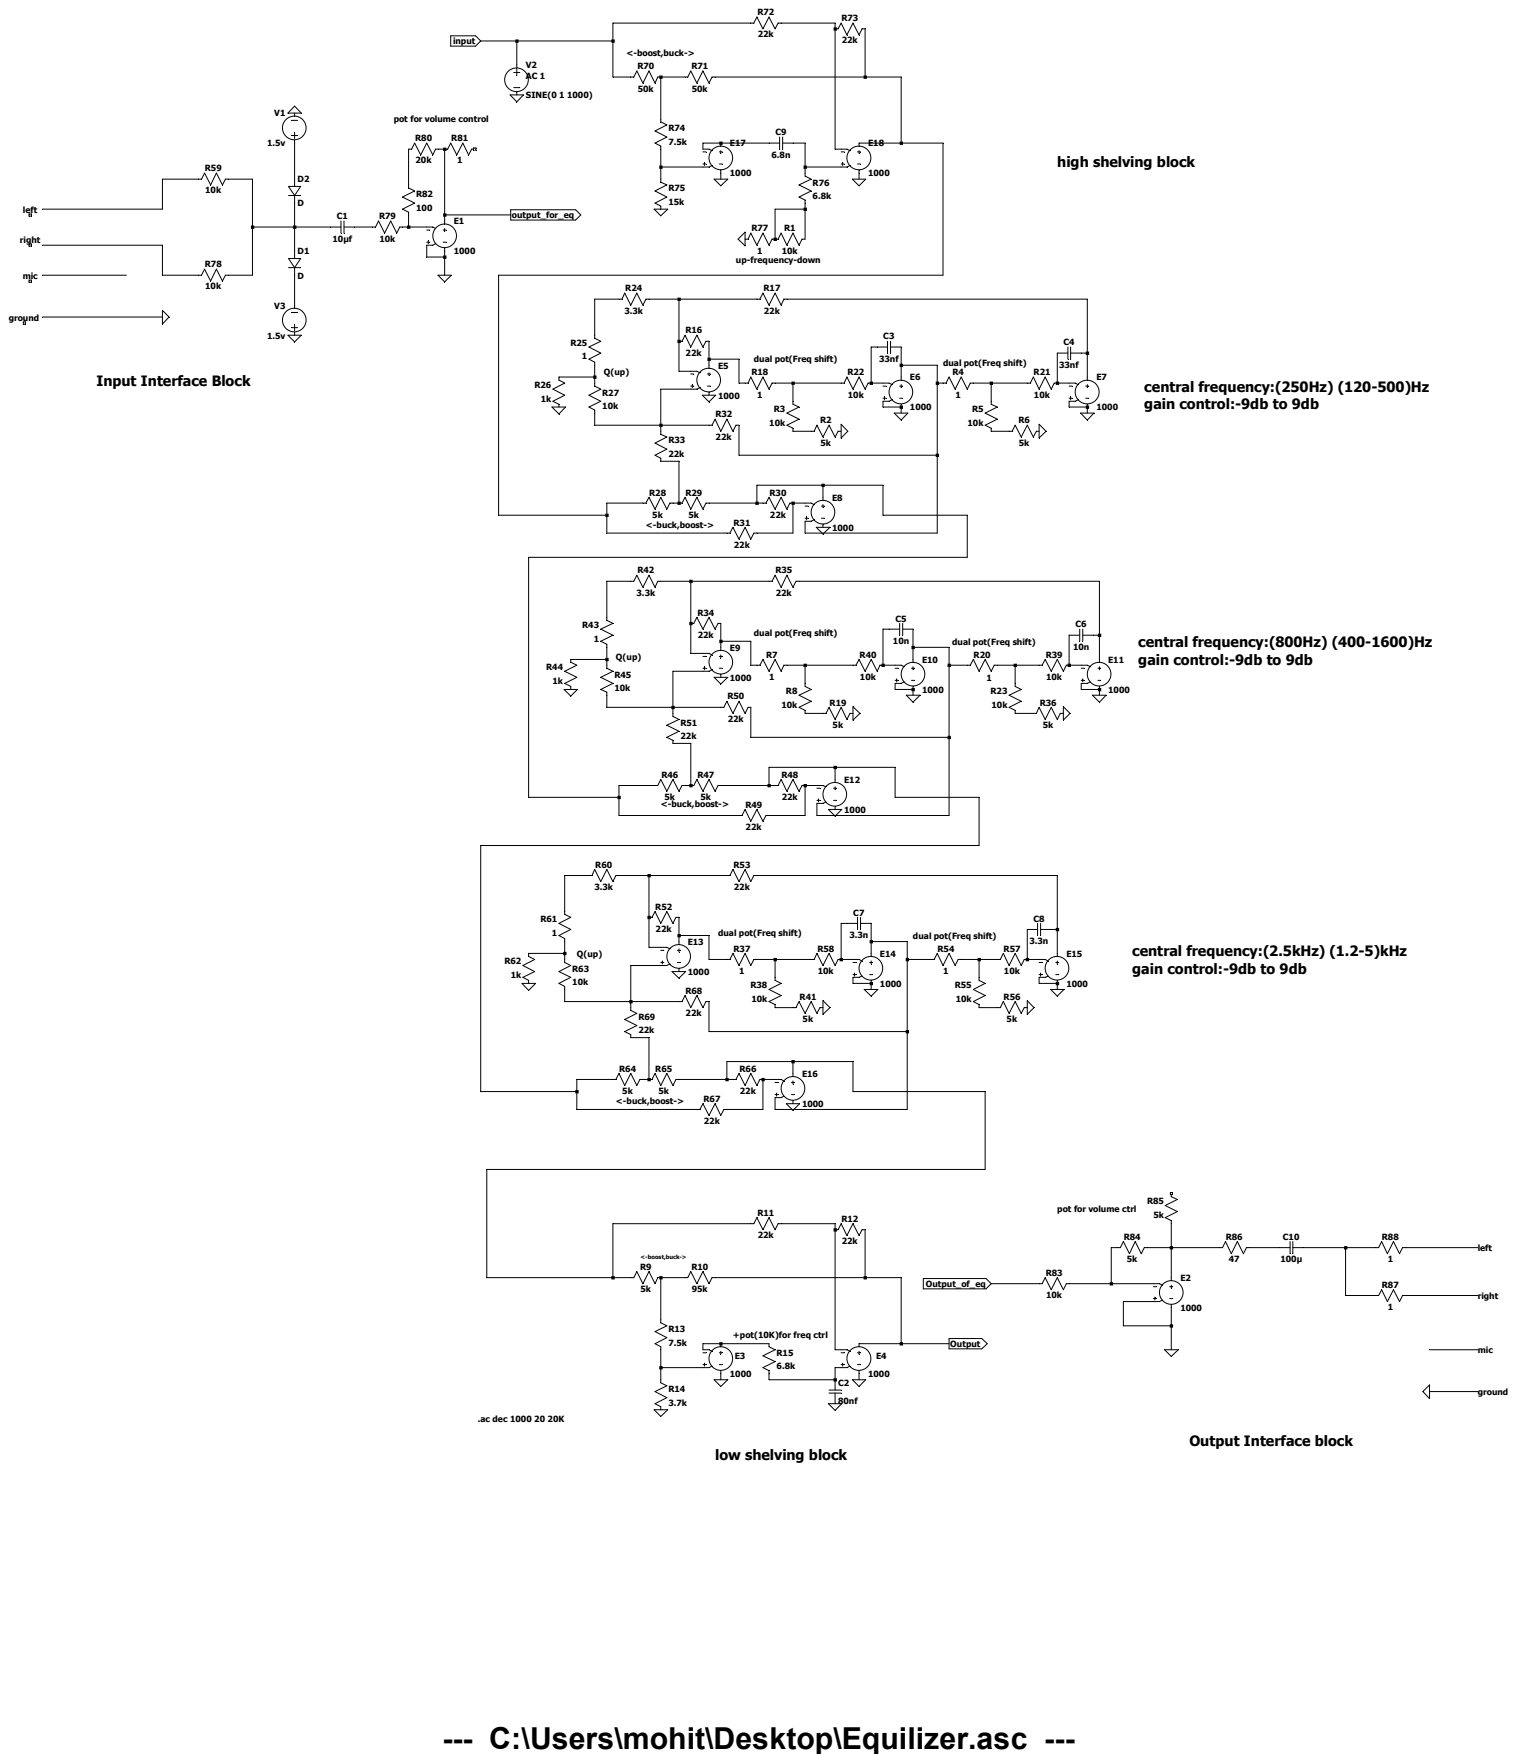
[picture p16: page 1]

pot for volume control

dual pot(Freq shift)

pot for volume ctrl

+pot(10K)for freq ctrl

--- C:\Users\mohit\Desktop\Equilizer.asc ---

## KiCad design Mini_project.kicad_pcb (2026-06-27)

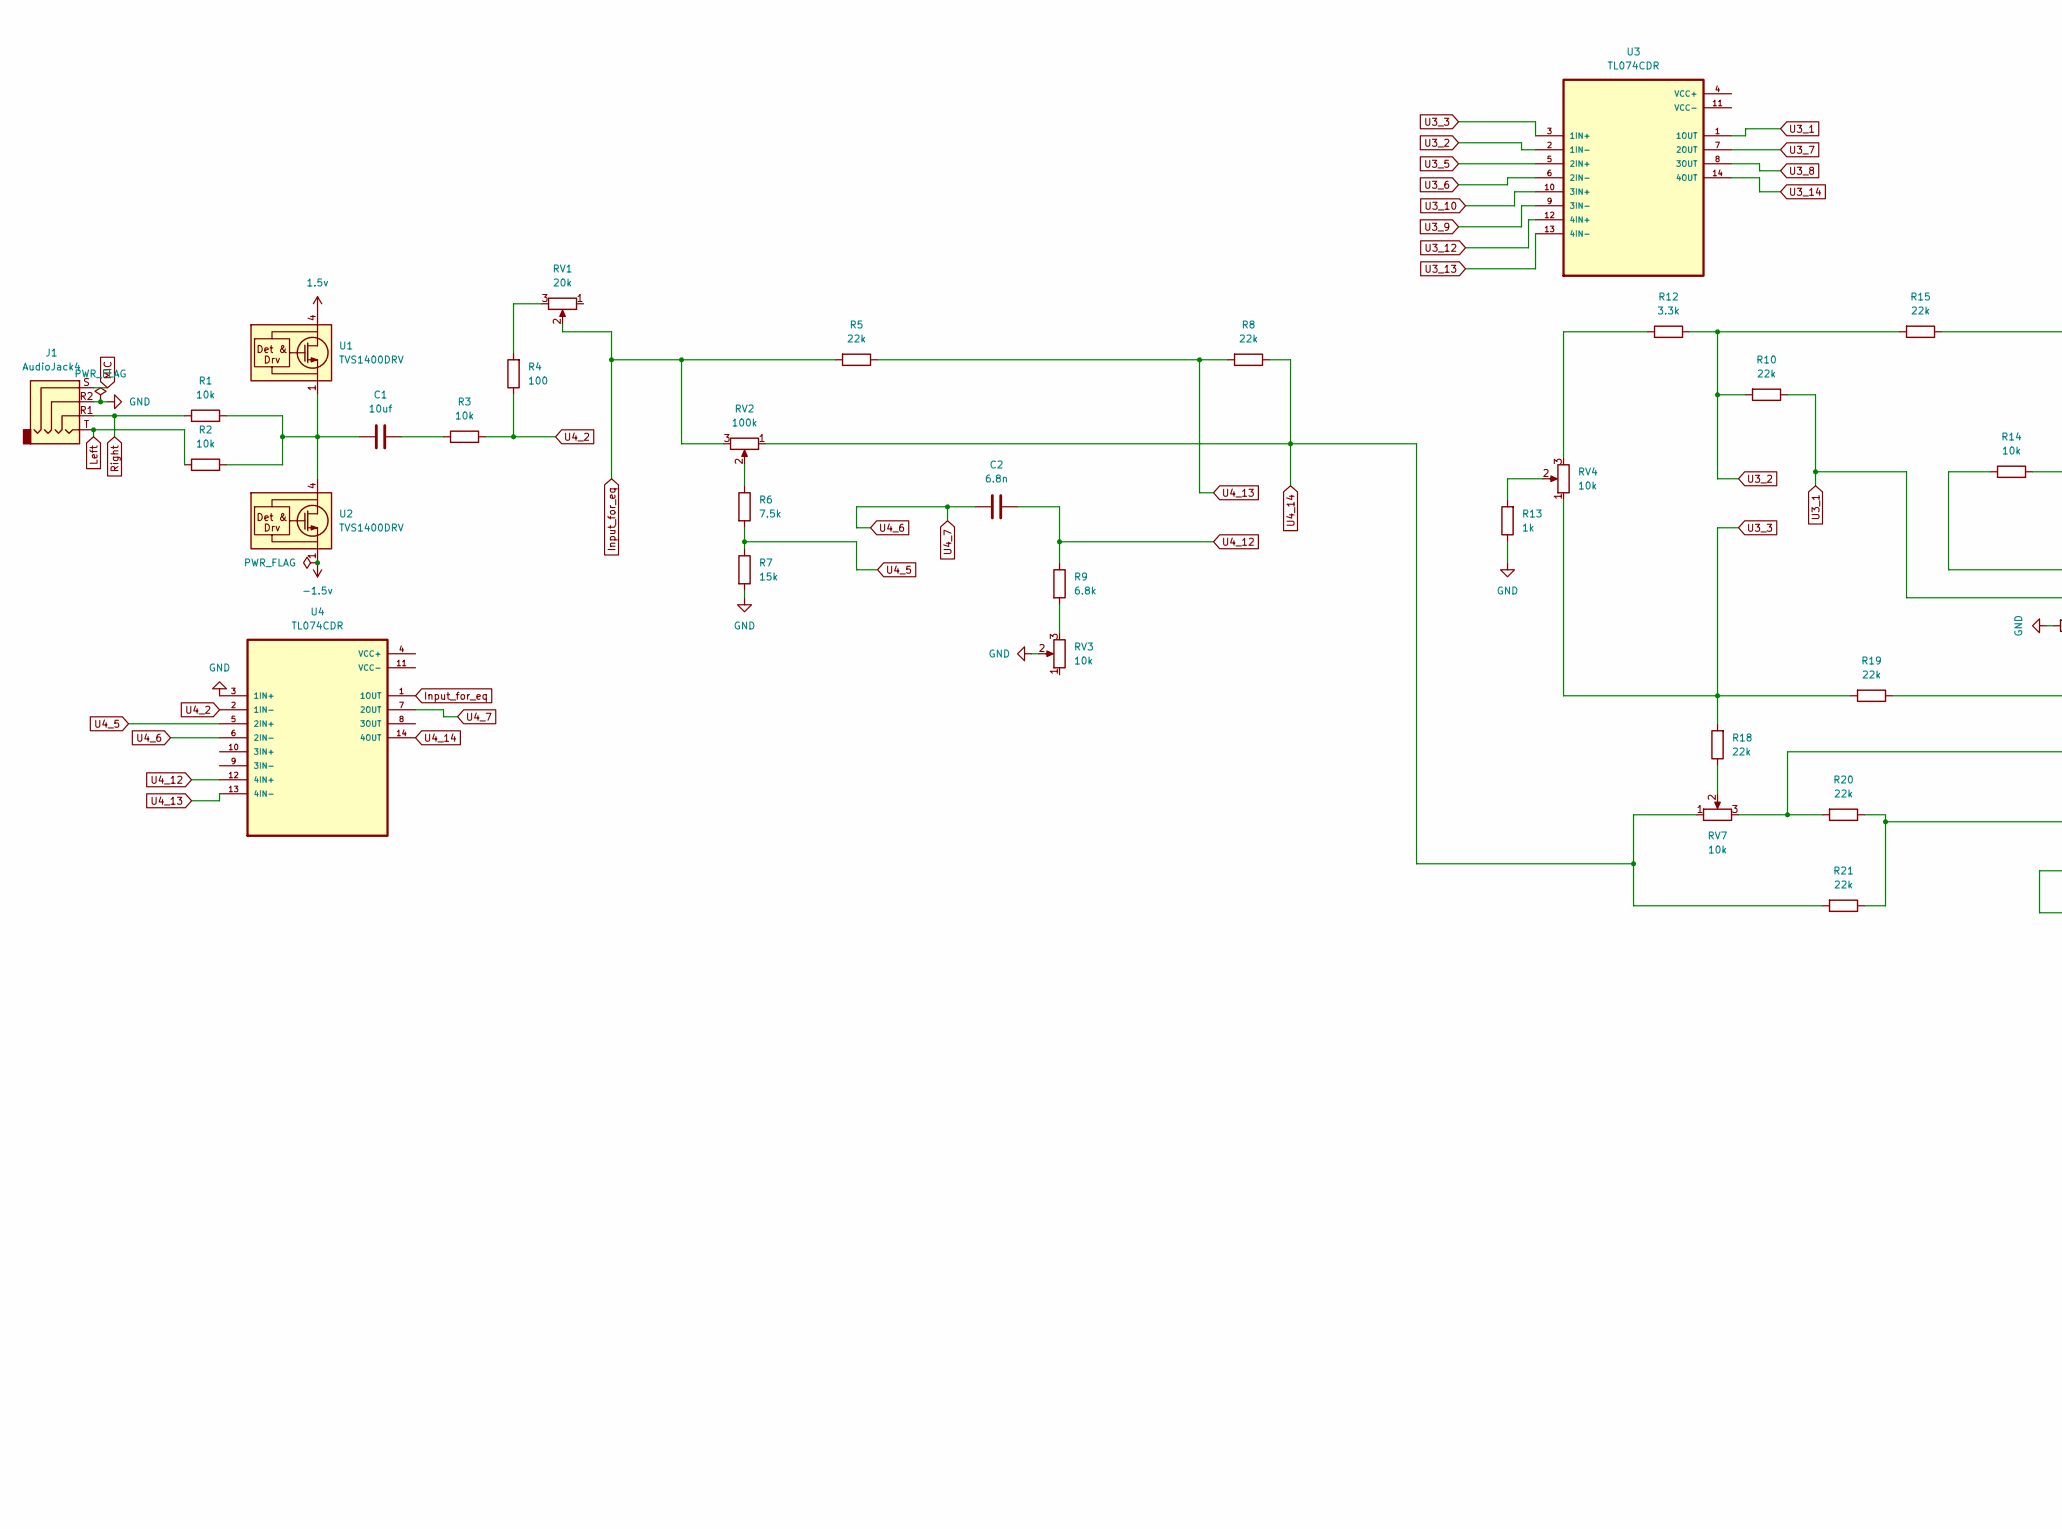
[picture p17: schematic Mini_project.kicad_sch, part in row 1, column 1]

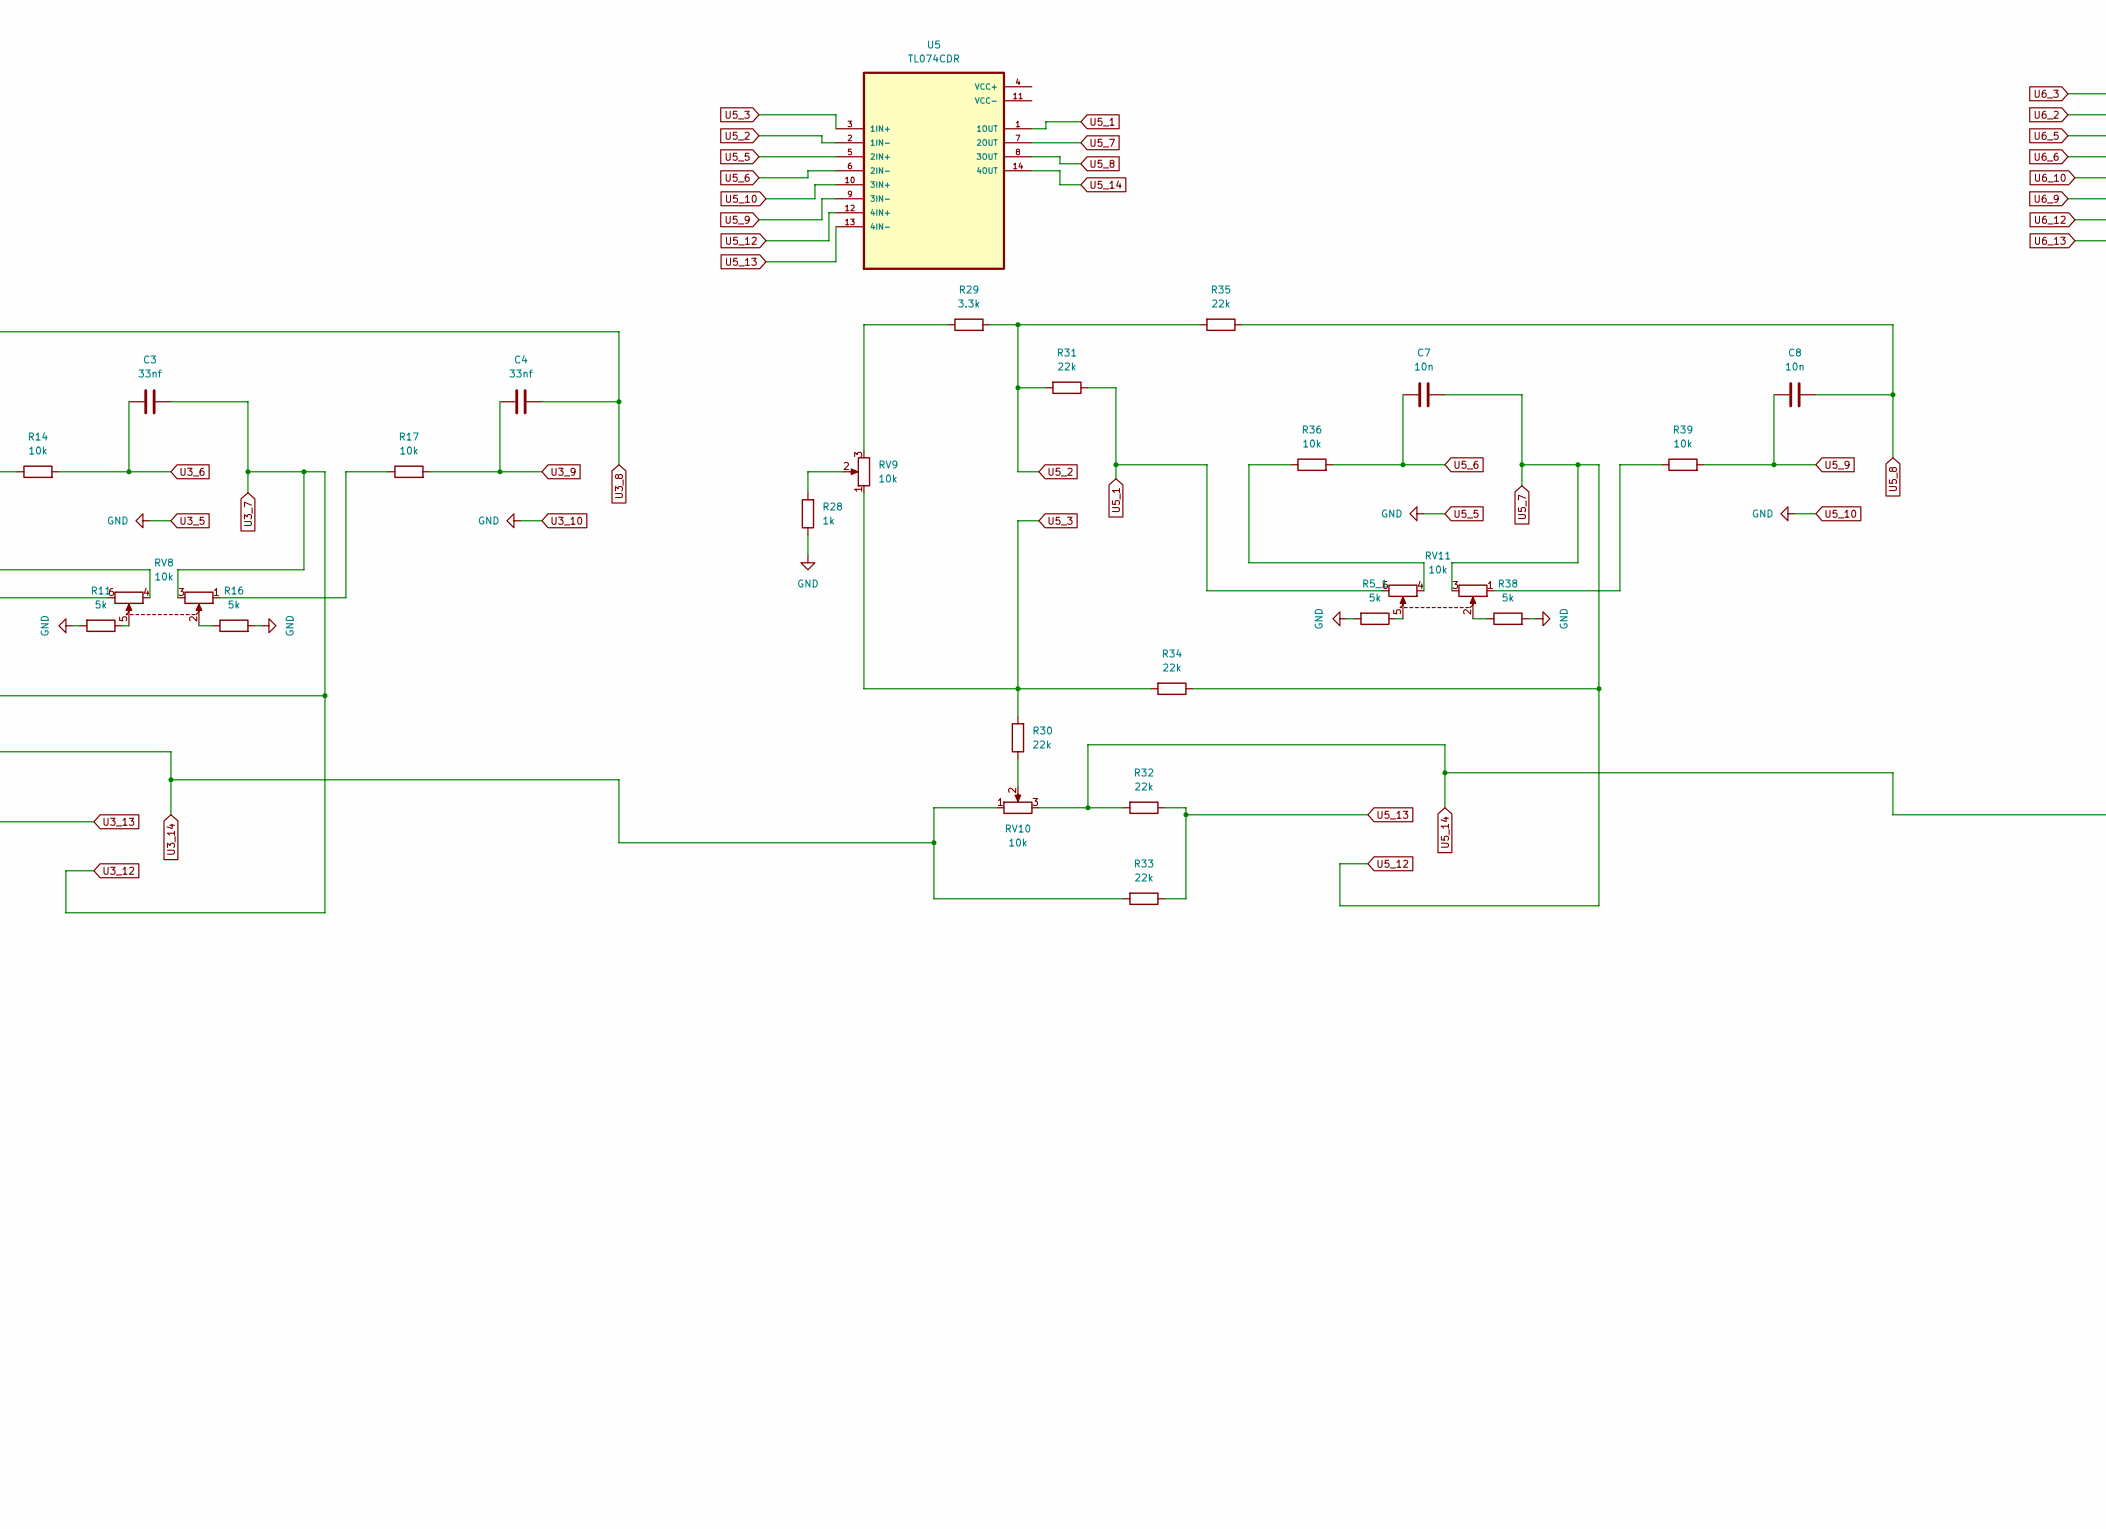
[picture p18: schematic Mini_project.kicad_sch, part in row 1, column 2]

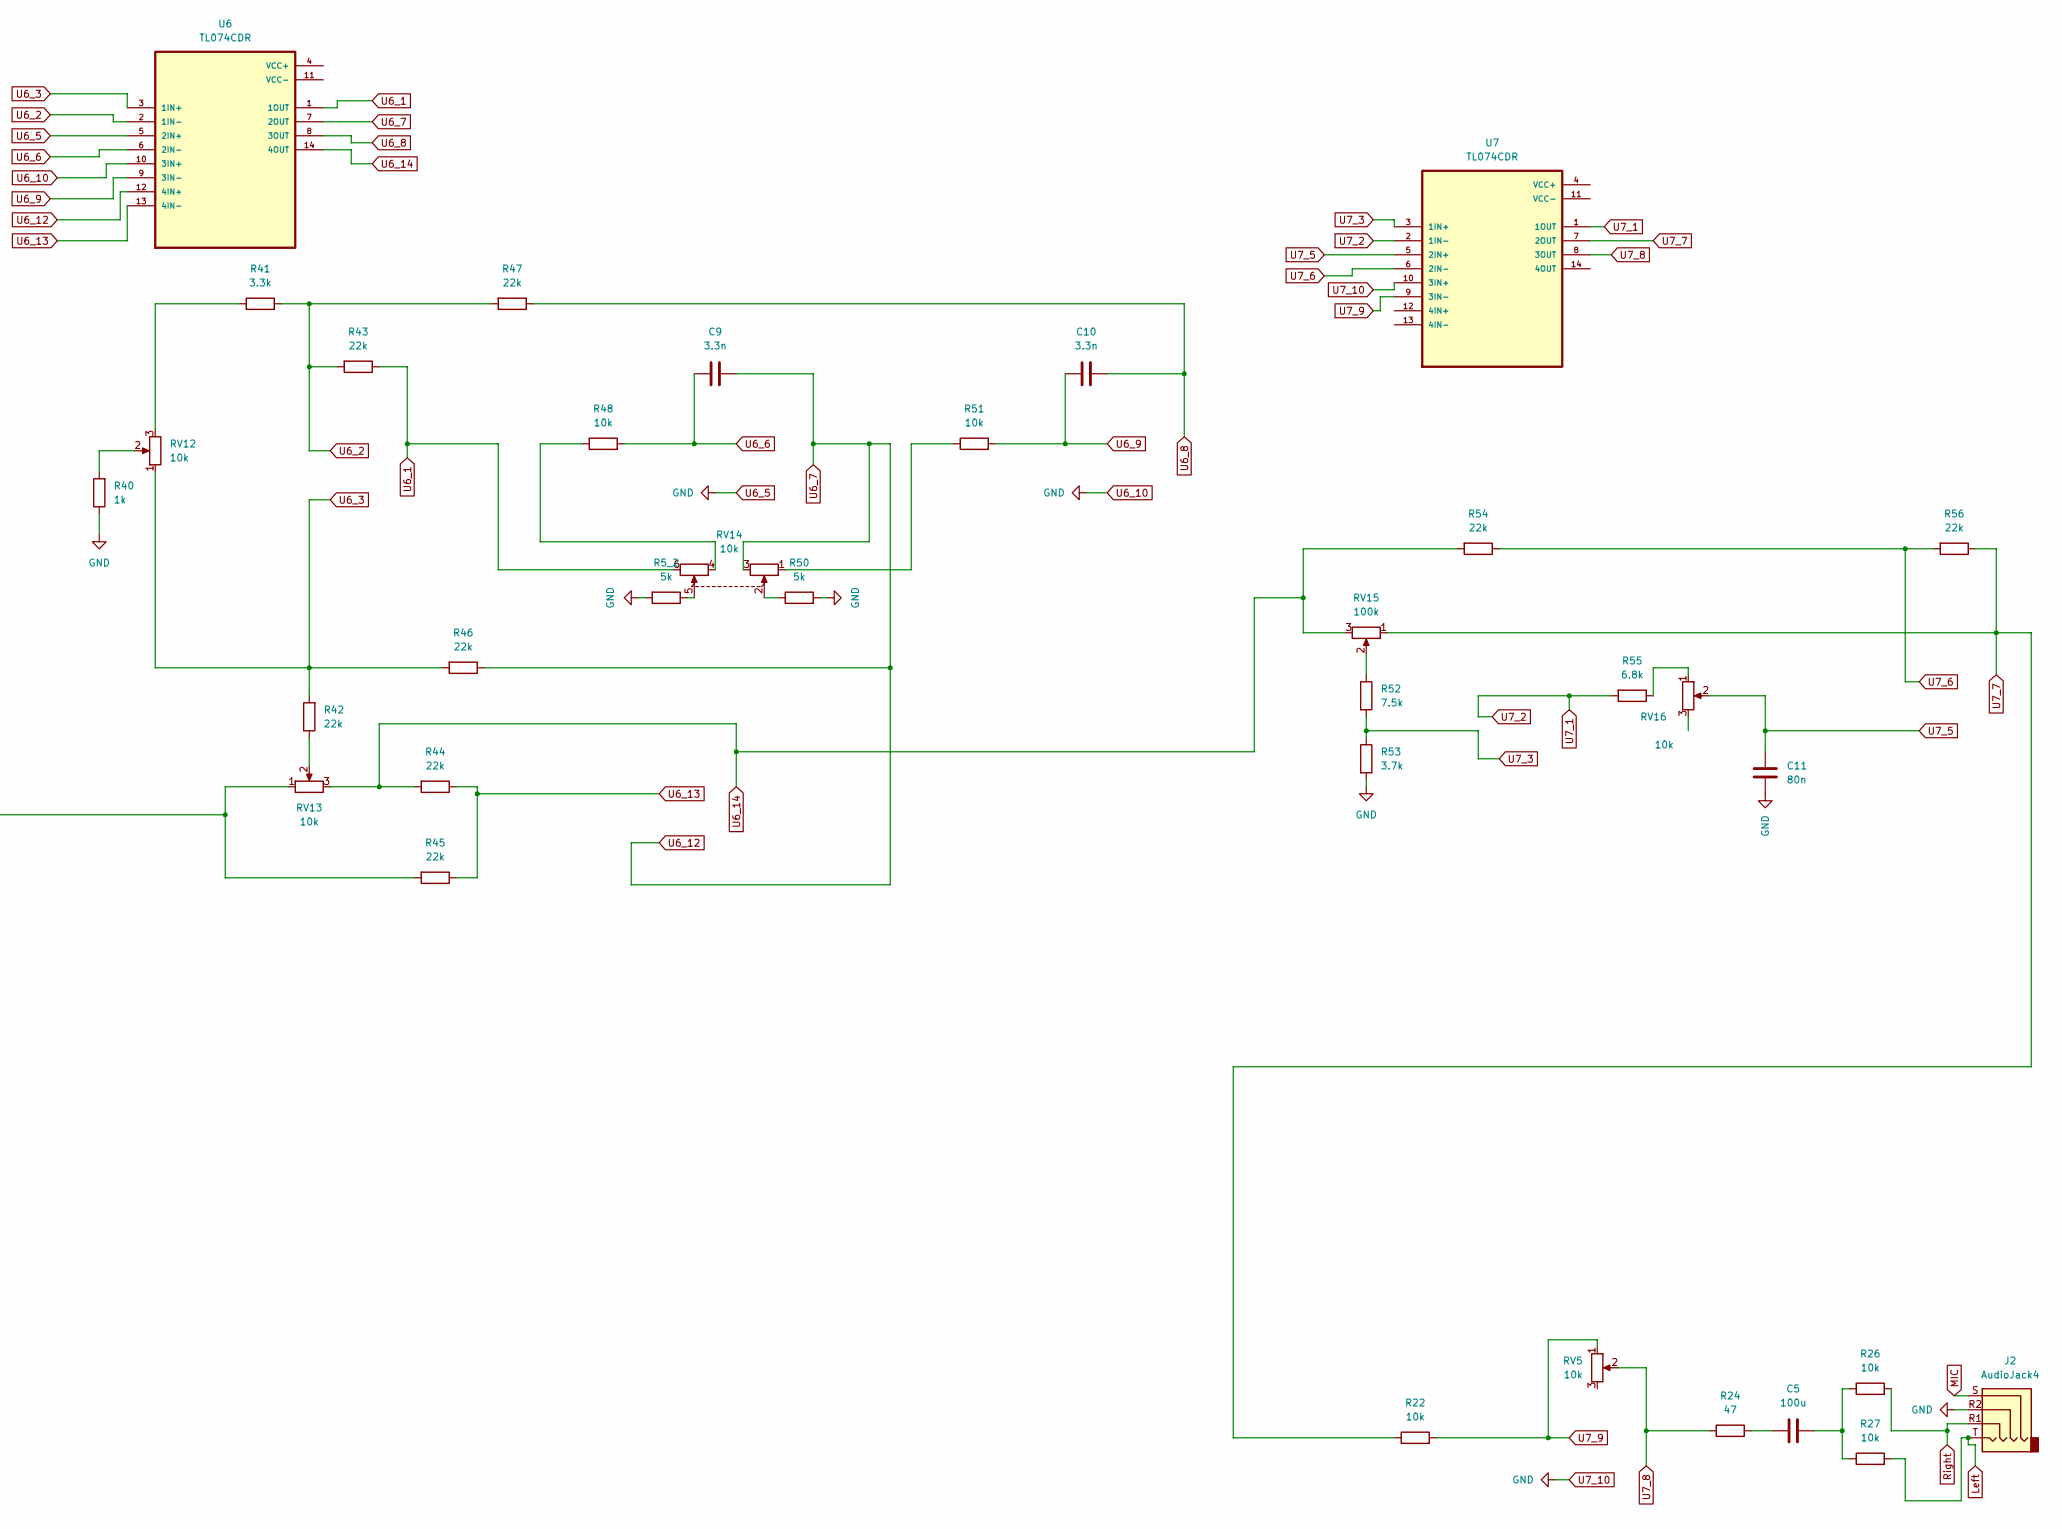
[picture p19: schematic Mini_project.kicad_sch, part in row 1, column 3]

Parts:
C1: 10uf; C_Trimmer_Murata_TZC3
C2: 6.8n; C_Trimmer_Murata_TZC3
C3, C4: 33nf; C_Trimmer_Murata_TZC3
C5: 100u; C_Trimmer_Murata_TZC3
C7, C8: 10n; C_Trimmer_Murata_TZC3
C9, C10: 3.3n; C_Trimmer_Murata_TZC3
C11: 80n; C_Trimmer_Murata_TZC3
J1, J2: AudioJack4; Jack_3.5mm_CUI_SJ-3524-SMT_Horizontal
R1, R2, R3, R14, R17, R22, R26, R27, R36, R39, R48, R51: 10k; R_0805_2012Metric
R4: 100; R_0805_2012Metric
R5, R8, R10, R15, R18, R19, R20, R21, R30, R31, R32, R33, R34, R35, R42, R43, R44, R45, R46, R47, R54, R56: 22k; R_0805_2012Metric
R5_1, R5_2, R11, R16, R38, R50: 5k; R_0805_2012Metric
R6, R52: 7.5k; R_0805_2012Metric
R7: 15k; R_0805_2012Metric
R9, R55: 6.8k; R_0805_2012Metric
R12, R29, R41: 3.3k; R_0805_2012Metric
R13, R28, R40: 1k; R_0805_2012Metric
R24: 47; R_0805_2012Metric
R53: 3.7k; R_0805_2012Metric
RV1: 20k; Potentiometer_Alpha_RD901F-40-00D_Single_Vertical
RV2, RV15: 100k; Potentiometer_Alpha_RD901F-40-00D_Single_Vertical
RV3, RV4, RV5, RV7, RV9, RV10, RV12, RV13, RV16: 10k; Potentiometer_Alpha_RD901F-40-00D_Single_Vertical
RV8, RV11, RV14: 10k; Potentiometer_Alpha_RD902F-40-00D_Dual_Vertical
U1, U2: TVS1400DRV; WSON-6-1EP_2x2mm_P0.65mm_EP1x1.6mm
U3, U4, U5, U6, U7: TL074CDR; SOIC127P600X175-14N

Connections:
1.5v: U1.4 (IN), U1.5 (IN), U1.6 (IN)
-1.5v: U2.1 (GND), U2.2 (GND), U2.3 (GND), U2.7 (GND)
Input_for_eq: R5.2, RV1.2, RV2.3, U4.1 (1OUT)
Left: J1.T, J2.T, R2.1, R27.2
MIC: J1.S, J2.S
unnamed: C1.1, R1.2, R2.2, U1.1 (GND), U1.2 (GND), U1.3 (GND), U1.7 (GND), U2.4 (IN), U2.5 (IN), U2.6 (IN)
unnamed: C1.2, R3.1
unnamed: C5.1, R24.2
unnamed: C5.2, R26.1, R27.1
unnamed: R4.2, RV1.3
unnamed: R5_1.1, RV11.5
unnamed: R5_2.1, RV14.5
unnamed: R6.1, RV2.2
unnamed: R9.2, RV3.3
unnamed: R11.1, RV8.5
unnamed: R12.1, RV4.3
unnamed: R13.2, RV4.2
unnamed: R14.1, RV8.4
unnamed: R16.1, RV8.2
unnamed: R17.1, RV8.1
unnamed: R18.1, RV7.2
unnamed: R28.2, RV9.2
unnamed: R29.1, RV9.3
unnamed: R30.1, RV10.2
unnamed: R36.1, RV11.4
unnamed: R38.1, RV11.2
unnamed: R39.1, RV11.1
unnamed: R40.2, RV12.2
unnamed: R41.1, RV12.3
unnamed: R42.1, RV13.2
unnamed: R48.1, RV14.4
unnamed: R50.1, RV14.2
unnamed: R51.1, RV14.1
unnamed: R52.1, RV15.2
unnamed: R55.1, RV16.1
Right: J1.R1, J2.R1, R1.1, R26.2
U3_1: R10.1, RV8.6, U3.1 (1OUT)
U3_2: R10.2, R12.2, R15.2, U3.2 (1IN-)
U3_3: R18.2, R19.2, RV4.1, U3.3 (1IN+)
U3_6: C3.1, R14.2, U3.6 (2IN-)
U3_8: C4.2, R15.1, U3.8 (3OUT)
U3_9: C4.1, R17.2, U3.9 (3IN-)
U3_10: C11.1, J1.R2, J2.R2, R5_1.2, R5_2.2, R7.2, R11.2, R13.1, R16.2, R28.1, R38.2, R40.1, R50.2, R53.2, RV3.2, U3.5 (2IN+), U3.10 (3IN+), U4.3 (1IN+), U5.5 (2IN+), U5.10 (3IN+), U6.5 (2IN+), U6.10 (3IN+), U7.10 (3IN+)
U3_12: C3.2, R19.1, RV8.3, U3.7 (2OUT), U3.12 (4IN+)
U3_13: R20.1, R21.1, U3.13 (4IN-)
U3_14: R20.2, R33.2, RV7.3, RV10.1, U3.14 (4OUT)
U4_2: R3.2, R4.1, U4.2 (1IN-)
U4_5: R6.2, R7.1, U4.5 (2IN+)
U4_6: C2.1, U4.6 (2IN-), U4.7 (2OUT)
U4_12: C2.2, R9.1, U4.12 (4IN+)
U4_13: R5.1, R8.2, U4.13 (4IN-)
U4_14: R8.1, R21.2, RV2.1, RV7.1, U4.14 (4OUT)
U5_1: R31.1, RV11.6, U5.1 (1OUT)
U5_2: R29.2, R31.2, R35.2, U5.2 (1IN-)
U5_3: R30.2, R34.2, RV9.1, U5.3 (1IN+)
U5_6: C7.1, R36.2, U5.6 (2IN-)
U5_8: C8.2, R35.1, U5.8 (3OUT)
U5_9: C8.1, R39.2, U5.9 (3IN-)
U5_12: C7.2, R34.1, RV11.3, U5.7 (2OUT), U5.12 (4IN+)
U5_13: R32.1, R33.1, U5.13 (4IN-)
U5_14: R32.2, R45.2, RV10.3, RV13.1, U5.14 (4OUT)
U6_1: R43.1, RV14.6, U6.1 (1OUT)
U6_2: R41.2, R43.2, R47.2, U6.2 (1IN-)
U6_3: R42.2, R46.2, RV12.1, U6.3 (1IN+)
U6_6: C9.1, R48.2, U6.6 (2IN-)
U6_8: C10.2, R47.1, U6.8 (3OUT)
U6_9: C10.1, R51.2, U6.9 (3IN-)
U6_12: C9.2, R46.1, RV14.3, U6.7 (2OUT), U6.12 (4IN+)
U6_13: R44.1, R45.1, U6.13 (4IN-)
U6_14: R44.2, R54.2, RV13.3, RV15.3, U6.14 (4OUT)
U7_1: R55.2, U7.1 (1OUT), U7.2 (1IN-)
U7_3: R52.2, R53.1, U7.3 (1IN+)
U7_5: C11.2, RV16.2, U7.5 (2IN+)
U7_6: R54.1, R56.2, U7.6 (2IN-)
U7_7: R22.1, R56.1, RV15.1, U7.7 (2OUT)
U7_8: R24.1, RV5.2, U7.8 (3OUT)
U7_9: R22.2, RV5.1, U7.9 (3IN-)

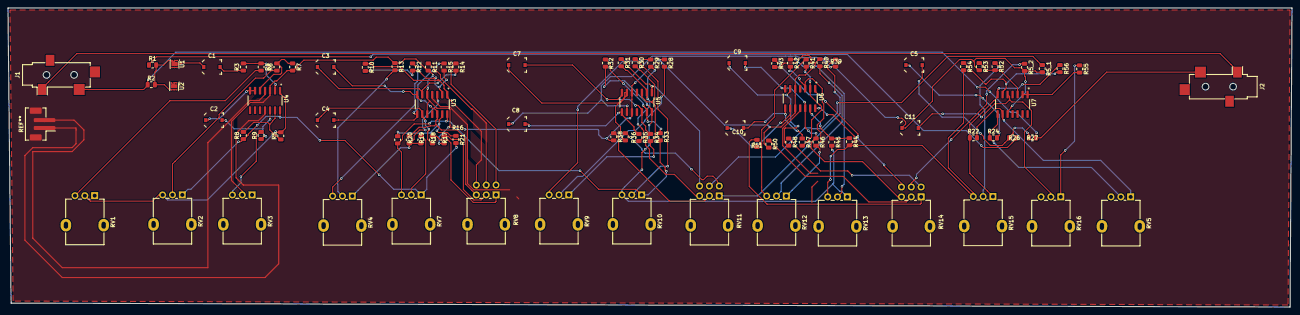
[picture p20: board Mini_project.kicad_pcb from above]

Board: 4 copper layers, 326.3 x 76.0 mm, 88 parts (0 on the bottom side), 77 nets.
